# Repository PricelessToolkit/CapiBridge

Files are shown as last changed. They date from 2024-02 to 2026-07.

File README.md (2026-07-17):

<div align="center">
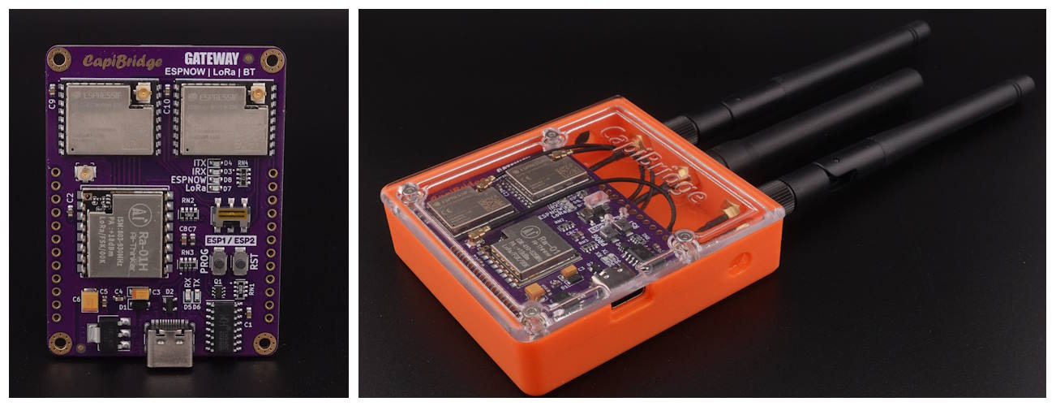
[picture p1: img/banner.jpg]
CapiBridge
  

🤗 Please consider subscribing to my YouTube channel. Your subscription goes a long way toward supporting my work. If you would like to contribute even more, you can also buy me a coffee.
  
  [Shop](https://www.pricelesstoolkit.com) | [YouTube](https://www.youtube.com/watch?v=mJt_VbMeRAU)
  
</div>
<p align="center">
  <a href="https://ko-fi.com/U6U2QLAF8">
    
  </a>
</p>

____________

CapiBridge is an open-source Two-Way gateway for low-power devices. It supports various communication technologies, including LoRa, ESP-NOW, and WiFi. The gateway receives JSON strings from LoRa and ESP-NOW Sensors or DIY devices and publishes them to an MQTT server. It automatically separates the JSON string into dynamic MQTT topics based on keys within the JSON, such as "b" for battery or "m" for motion, making it highly compatible with Home Assistant. This gateway simplifies adding new DIY nodes/sensors to your smart home by standardizing the communication protocol across all your DIY projects, focusing on simplicity and unified protocol handling.

### 🚀 NEW WebUI for Configuration and Monitoring
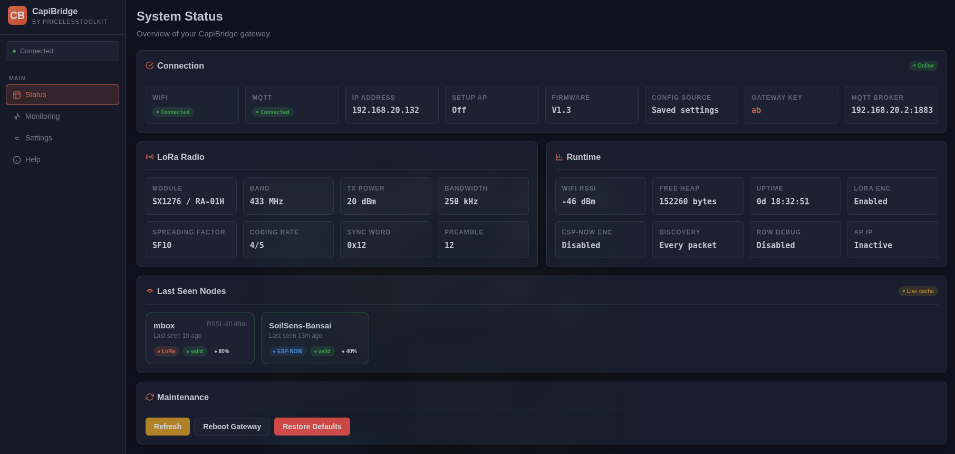
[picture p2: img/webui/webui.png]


____________

## 🛒 Where to buy http://www.PricelessToolkit.com

### Sensors that work out of the box with CapiBridge.
 - [PirBOX-LITE](https://github.com/PricelessToolkit/PirBOX-LITE) LoRa Long-Range Motion Sensor for Mailbox/Garage.....
 - [PirBOX-MAX](https://github.com/PricelessToolkit/PirBOX-MAX) LoRa Long-Range 2-Way Motion Sensor with reed switch inputs and relays
 - [SOILSENS-V5W](https://github.com/PricelessToolkit/SOILSENS-V5W) Soil Moisture Sensor

____________

## Specifications
- 1x LoRa Module 868 or 433MHz
- 2x ESP32-C3
 - ESP1 Free GPIOs
   - IO7, IO10
 - ESP2 Free GPIOs
   - IO10, IO3, IO1, IO0, IO4, IO5, IO6, IO7
- Power Pins 5V, 3.3V, GND
- USB-C with auto reset
- UART switch for selecting ( ESP1 | ESP2 )
- Buttons for flashing and resetting
- Debug LEDs
  - USB - TX, RX
  - ESP1 to ESP2 - TX, RX
  - One LED for LoRa
  - One LED for ESP-NOW

> [!IMPORTANT]
> A high-quality phone charger should be used to ensure a stable 5V power supply.
____________

## 📣 Updates, Bugfixes, and Breaking Changes
- 17.04.2026
  - WebUI for configuration and monitoring.
- 28.03.2026
  - Added support for "Ra-01S" 433Mhz Module.
  - `#define LORA_MODULE LORA_MODULE_SX1268    // Ra-01S 433Mhz Module "433Mhz Version" Module CapiBridge v2`

____________

## Before you start
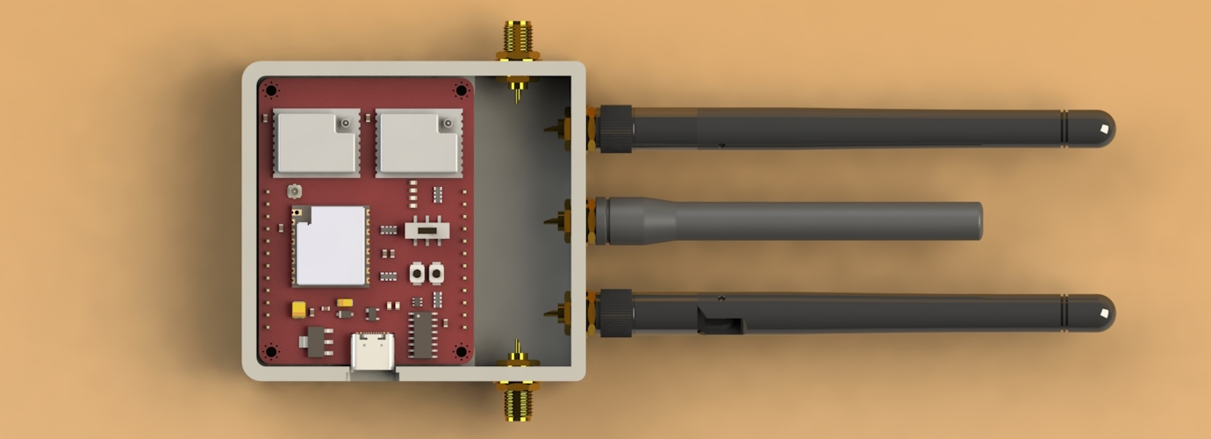
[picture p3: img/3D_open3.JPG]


> [!WARNING]
> ### 🔥Connect all antennas first to prevent damage to the transmitter.🔥

> [!IMPORTANT]
> If you're new to Arduino-related matters, please refrain from asking basic questions like "how to install Arduino IDE". There are already plenty of excellent tutorials available on the internet. If you encounter any issues to which you can't find the answer -> [Here](https://www.google.com/) , feel free to join our [Facebook Group](https://www.facebook.com/groups/pricelesstoolkit) or open a new [discussion](https://github.com/PricelessToolkit/CapiBridge/discussions) topic in the dedicated tab. Remember that providing detailed information about the problem will help me offer more effective assistance. More information equals better help!

## Arduino IDE Configuration

> [!NOTE]
> Arduino IDE 2.3.2

#### Used Arduino Libraries
```c
#include <Arduino.h>
#include <SPI.h>
#include <RadioLib.h>
#include <WiFi.h>
#include <PubSubClient.h>
#include <ArduinoJson.h>
#include <esp_now.h>
```

CapiBridge is based on ESP32-C3, so if you are using ESP32 for the first time, you need to install the ESP32 board and all libraries in your Arduino IDE.
- In your Arduino IDE, go to File> Preferences.
- Enter `https://raw.githubusercontent.com/espressif/arduino-esp32/gh-pages/package_esp32_index.json` into the “Additional Boards Manager URLs” field. Then, click the “OK” button
- Open the Boards Manager. Go to Tools > Board > Boards Manager and search for ESP32 and press the install button for the “esp32 by Expressif Systems“
- Open Library Manager, search for PubSubClient and press the install button, do the same for other libraries.

____________

## ESP1.ino sketch configuration

> [!NOTE]
> For `ESP1.ino`
> Initial configurations are done in the file `config.h` and the rest in WebUI.

#### Initial Configuration

```cpp
///////////////////////////////////////////////////////////////////////////////

//#define LORA_MODULE LORA_MODULE_SX1276    // Ra-01 433 Ra-01H 868/915Mhz "SX1276" Module (orders shipped before Aug 2025)
#define LORA_MODULE LORA_MODULE_SX1262      // Ra-01SH 868/915Mhz "SX1262"  Module CapiBridge v2
//#define LORA_MODULE LORA_MODULE_SX1268    // Ra-01S 433Mhz Module "433Mhz Version" Module CapiBridge v2

#define BAND 868.0                          // 433.0 / 868.0 / 915.0

#define WEBUI_PASSWORD "password"           // Web UI password protection
#define WEBUI_USERNAME "admin"              // Login for the Web UI

#define WIFI_SSID "Your-WIFI-Name"
#define WIFI_PASSWORD "WIFI-Password"

//////////////////////////////////////////////////////////////////////////////

```

## Uploading Code to CapiBridge
> [!WARNING]
> ### 🔥Connect the antenna first to prevent damage to the transmitter.🔥

1. Open ESP1.ino sketch and configure config.h file see https://github.com/PricelessToolkit/CapiBridge?tab=readme-ov-file#esp1ino-sketch-configuration
2. Set the UART switch on the CapiBridge to the 'ESP1' position.
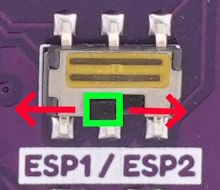
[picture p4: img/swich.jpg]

3. Select board type, COM port and... see the screenshot below.

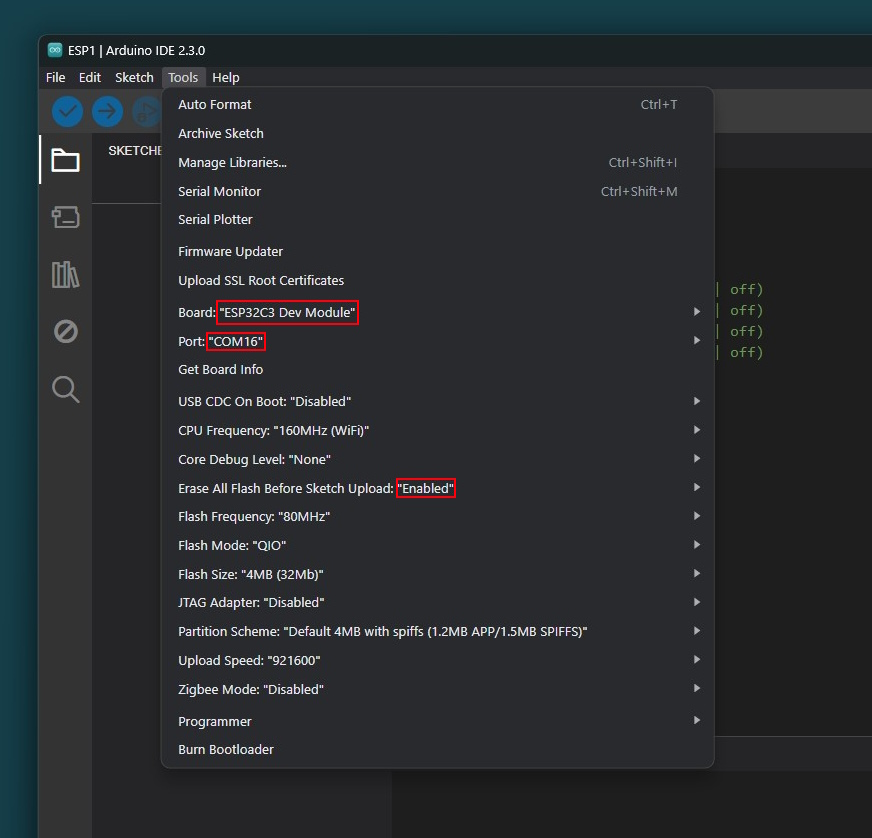
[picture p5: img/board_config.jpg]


4. Click Upload and wait until the upload is done.
5. Set the UART switch on the CapiBridge to the 'ESP2' position.


6. Open ESP2.ino sketch.

> [!NOTE]
> ESP2 for `ESPNOW` requires no initial setup. Once the sketch is uploaded, it automatically prints the MAC address in the serial monitor for integration with ESPNOW nodes/sensors.

8. Click Upload.
9. Set the UART switch back to the ESP1 position to see received JSON messages.

Everything will be ready shortly; the CapiBridge RSSI entity should appear in the Home Assistant MQTT devices list within a minute or two.

> [!NOTE]
> After uploading the code, open the Configuration webpage http://YOUR-CAPIBRIDGE-IP
> and configure the rest.

#### Gateway Separation and Encryption Keys

> [!IMPORTANT]
> Unique `GATEWAY_KEY` within the JSON to differentiate your data from others, and `encryption_key` to globally encrypt the payload. Must match the key in Nodes/Sensors.
> 

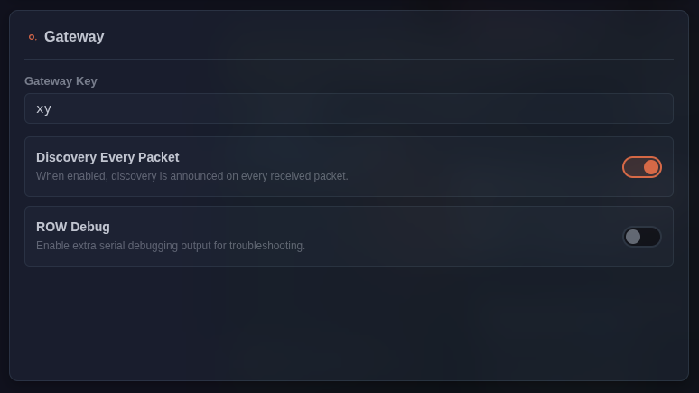
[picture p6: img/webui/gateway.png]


#### 🔐 How to Create Your `encryption_key` Using a Calculator

1. **Choose a few numbers between `1` and `255`**  
   These will be your secret key values.  
   **Example:** `5`, `162`, `77`, `33`

2. **Open your calculator:**
   - **Windows:** Open the **Calculator app** → Click the **☰ menu** → Choose **Programmer**
   - Or use any online converter (Google: _"decimal to hex converter"_)

3. **Convert each number to HEX:**
   - Type your decimal number (e.g., `5`)
   - Switch to **HEX mode**
   - You’ll see the result (e.g., `0x05`)

4. **Use the converted HEX values in WEBUI:**

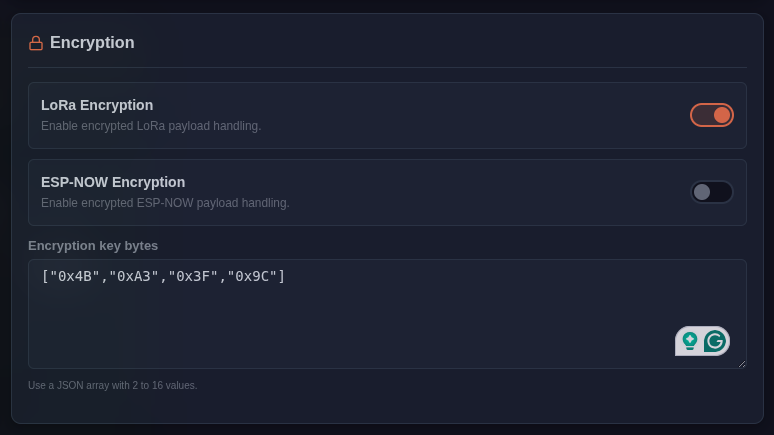
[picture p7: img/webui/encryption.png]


#### WIFI Configuration

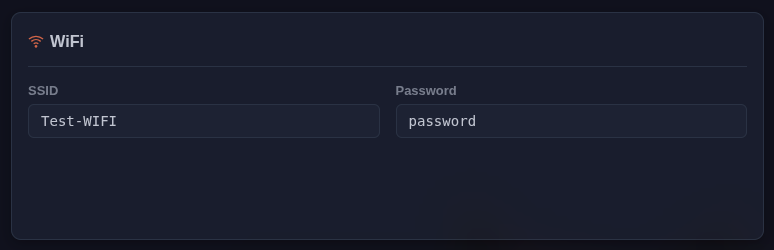
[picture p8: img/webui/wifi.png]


#### MQTT Server Configuration

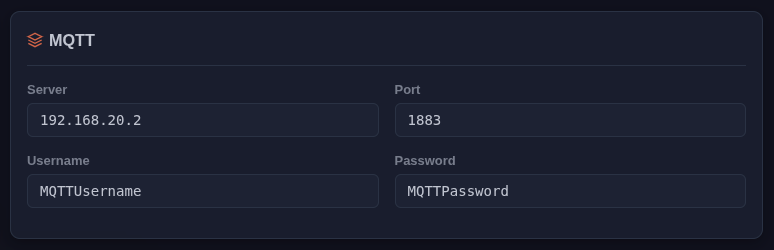
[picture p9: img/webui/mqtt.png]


#### LoRa Configuration

> [!IMPORTANT]
> LoRa configuration must match the configuration in Nodes/Sensors.

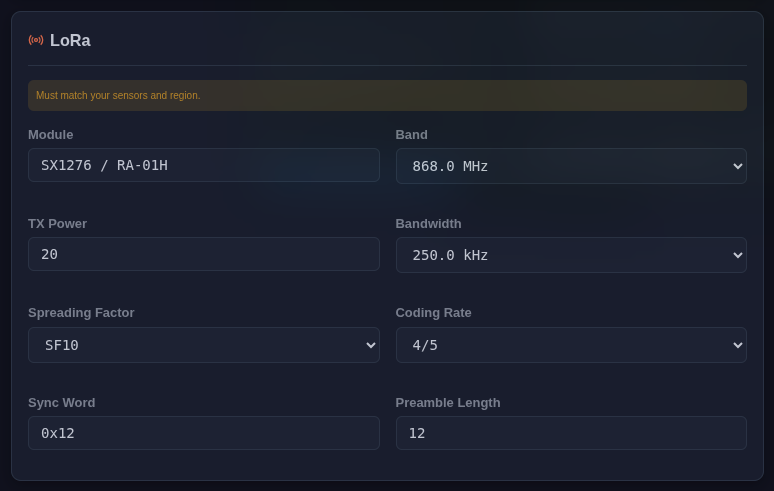
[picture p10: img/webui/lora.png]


> [!IMPORTANT]
> For optimizing the `SPREADING_FACTOR` (SF) in your network, it's crucial not to default to SF11, aiming for maximum distance without considering its downsides. SF11, while extending range, significantly slows down data transmission. For example, if your furthest sensor is only 100 meters away, opting for SF7 is more efficient. SF7 is faster, consuming less power compared to SF11. Therefore, it's essential to choose the SF wisely based on your specific needs and understand the trade-offs. Avoid setting SF11 by default without assessing the impact on speed, power consumption, and time on air (ToA) for others.

____________

## Home Assistant Zero Configuration
> [!NOTE]
> With MQTT-Autodiscovery, there's no need to configure anything in Home Assistant manually. Any sensor or node that sends a JSON string with special keys `('k' for the gateway private key and 'id' for the node name, both of which are mandatory)` will be automatically discovered. Refer to the table below for details, and of course, full ESP32 examples are provided.

## JSON String Sent by a Sensor/Node:

```json
{
  "k": "xy",
  "id": "ESP32",
  "b": "99",
  "rw": "Test123",
  "dr": "on"
}
```
Full Suported MQTT-Autodiscovery List

| Key | Description | Unit of Measurement | Required |
|---|---|---|---|
| `k` | Private Gateway key |  - | Yes |
| `id`  | Node Name |  - | Yes |
| `r` | RSSI | dBm | No |
| `b` | Battery percent | % | No |
| `v` | Voltage | Volts | No |
| `pw`  | Current | mAh | No |
| `l` | Luminance | lux | No |
| `m` | Motion | Binary on/off | No |
| `w` | Weight | grams | No |
| `s` | State | Anything | No |
| `t` | Temperature | °C | No |
| `t2`  | Temperature 2 | °C | No |
| `hu`  | Humidity | % | No |
| `mo`  | Moisture | % | No |
| `rw`  | ROW | Anything | No |
| `bt`  | Button | Binary on/off | No |
| `atm` | Pressure | kph | No |
| `cd`  | Dioxyde de carbone | ppm | No |
| `dr`  | Door | Binary on/off | No |
| `wd`  | Window | Binary on/off | No |
| `vb`  | Vibration | Binary on/off | No |

## ESP-NOW Sensor Example (with optional XOR encryption)

This example broadcasts JSON sensor data from an ESP32 via **ESP-NOW**.  
You can **enable/disable XOR encryption** with a single switch.

- Broadcasts to `FF:FF:FF:FF:FF:FF`
- JSON includes `k` (gateway key) and `id` (device id), plus sample sensor fields
- **ENCRYPTION** toggle controls raw XOR in-place (gateway must use the same key)
- Keep payload under ~249 bytes

<details>
<summary>Minimal Example (with encryption toggle). Click here</summary>

```cpp
#include <Arduino.h>
#include <esp_now.h>
#include <WiFi.h>
#include <esp_wifi.h>
#include <ArduinoJson.h>

// ---------- USER SETTINGS ----------
#define DEVICE_ID            "TestESP"
#define GATEWAY_KEY          "xy"
#define ESPNOW_WIFI_CHANNEL  1
#define SEND_PERIOD_MS       5000

// XOR encryption toggle and key
#define ENCRYPTION 0   // 0 = off, 1 = on
#define encryption_key_length 4
#define encryption_key { 0x4B, 0xA3, 0x3F, 0x9C }
// -----------------------------------

// Broadcast MAC
static const uint8_t BROADCAST_MAC[6] = {0xFF,0xFF,0xFF,0xFF,0xFF,0xFF};
unsigned long lastSend = 0;

// XOR in place (raw bytes)
static inline void xorInPlace(uint8_t* data, size_t len) {
  static const uint8_t key[] = encryption_key;
  const size_t K = encryption_key_length;
  for (size_t i = 0; i < len; ++i) data[i] ^= key[i % K];
}

// Build small JSON payload (add your real sensor values)
static size_t buildSensorJson(char* out, size_t cap) {
  JsonDocument doc;          // ArduinoJson v7 style
  doc["k"]  = GATEWAY_KEY;   // REQUIRED: gateway private key
  doc["id"] = DEVICE_ID;     // REQUIRED: node/device id
  doc["t"]  = 21.5;          // temperature °C (example)
  doc["hu"] = 46;            // humidity %  (example)
  return serializeJson(doc, out, cap);
}

static bool sendBroadcast() {
  char buf[160];
  size_t len = buildSensorJson(buf, sizeof(buf));
  if (len == 0 || len >= sizeof(buf)) return false;

  // Optional debug: plaintext
  // Serial.write((const uint8_t*)buf, len); Serial.println();

  // Toggle XOR encryption
  #if ENCRYPTION
    xorInPlace(reinterpret_cast<uint8_t*>(buf), len);
  #endif

  return esp_now_send(BROADCAST_MAC, reinterpret_cast<const uint8_t*>(buf), len) == ESP_OK;
}

// Send callback (handles both IDF v4 and v5 cores)
#if defined(ESP_IDF_VERSION_MAJOR) && (ESP_IDF_VERSION_MAJOR >= 5)
void onDataSent(const wifi_tx_info_t*, esp_now_send_status_t status) {
  Serial.println(status == ESP_NOW_SEND_SUCCESS ? "SUCCESS" : "FAIL");
}
#else
void onDataSent(const uint8_t*, esp_now_send_status_t status) {
  Serial.println(status == ESP_NOW_SEND_SUCCESS ? "SUCCESS" : "FAIL");
}
#endif

void setup() {
  Serial.begin(115200);
  WiFi.persistent(false);
  WiFi.mode(WIFI_STA);
  esp_wifi_set_ps(WIFI_PS_NONE);
  esp_wifi_start();

  // Lock to gateway's Wi-Fi channel
  esp_wifi_set_promiscuous(true);
  esp_wifi_set_channel(ESPNOW_WIFI_CHANNEL, WIFI_SECOND_CHAN_NONE);
  esp_wifi_set_promiscuous(false);

  if (esp_now_init() != ESP_OK) {
    Serial.println("ESP-NOW init failed");
    while (true) delay(1000);
  }
  esp_now_register_send_cb(onDataSent);

  // Add broadcast peer (unencrypted at ESP-NOW level; XOR is app-layer)
  esp_now_peer_info_t peer{};
  memcpy(peer.peer_addr, BROADCAST_MAC, 6);
  peer.ifidx   = WIFI_IF_STA;
  peer.channel = ESPNOW_WIFI_CHANNEL;
  peer.encrypt = false;
  esp_now_add_peer(&peer);
}

void loop() {
  if (millis() - lastSend >= SEND_PERIOD_MS) {
    lastSend = millis();
    bool ok = sendBroadcast();
    Serial.println(ok ? "Sent" : "Send failed");
  }
}

```
</details>

👉 full example with all supported keys is available in the `Node_Examples` folder.

## LoRa Sensor Example (with optional XOR encryption)
You can find working code examples in the following repositories:  
- [MailBoxGuard for "CapiBridge"](https://github.com/PricelessToolkit/MailBoxGuard/blob/main/Code/CapiBridge/Mailbox_Guard_Sensor_CapiBridge/Mailbox_Guard_Sensor_CapiBridge.ino)
- [PirBOX-LITE](https://github.com/PricelessToolkit/PirBOX-LITE)  
- [PirBOX-MAX](https://github.com/PricelessToolkit/PirBOX-MAX)  

---

## XOR Encryption / Decryption Example

This snippet shows how to use a simple **XOR cipher** with ESP-NOW.  
Both sender and receiver must use the **same key**.

- `xorInPlace()` encrypts or decrypts data in-place.  
- Call it **before sending** to encrypt.  
- Call it **after receiving** to decrypt.  

---

```cpp
// --- XOR helper (must match on sender + receiver) ---
#define encryption_key_length 4
#define encryption_key { 0x4B, 0xA3, 0x3F, 0x9C }

static inline void xorInPlace(uint8_t* data, size_t len) {
  static const uint8_t key[] = encryption_key;
  const size_t K = encryption_key_length;
  for (size_t i = 0; i < len; ++i) data[i] ^= key[i % K];
}

// --- SENDER ---
void sendExample() {
  char msg[] = "hello world";
  size_t len = strlen(msg);

  // Encrypt before sending
  xorInPlace((uint8_t*)msg, len);
  esp_now_send(BROADCAST_MAC, (uint8_t*)msg, len);
}

// --- RECEIVER ---
void onDataRecv(const uint8_t* mac, const uint8_t* data, int len) {
  char buf[128];
  memcpy(buf, data, len);

  // Decrypt after receiving
  xorInPlace((uint8_t*)buf, len);
  buf[len] = '\0';  // make string safe

  Serial.print("Decrypted: ");
  Serial.println(buf);
}
```

---

## 🔁 2-Way Communication – Sending Commands

To send a command via **LoRa** or **ESP-NOW**, publish a JSON payload to the following MQTT topic:

```
homeassistant/sensor/CapiBridge/command
```

LoRa Payload

```json
{"k":"xy","id":"PirBoxM","rm":"lora","com":"xxxxxx"}
```
ESP-NOW payload
```json
{"k":"xy","id":"PirBoxM","rm":"espnow","com":"xxxxxx"}
```

Descriptions

| Key | Description | Example |
|---|---|---|
| `k` | Private gateway key (auth) | `"xy"` |
| `id`  | Target node name (device ID) | `"PirBoxM"` |
| `rm`  | Radio mode (`lora` / `espnow`)  | `"lora", "espnow"` |
| `com` | Command code (text/number) | `"xxxxxx"`  |

To send commands through the Home Assistant Dashboard, use the button example below.

```yaml

type: horizontal-stack
cards:
  - show_name: true
    show_icon: true
    type: button
    name: Relay 1
    icon: mdi:numeric-1-box
    tap_action:
      action: call-service
      service: mqtt.publish
      service_data:
        topic: homeassistant/sensor/CapiBridge/command
        payload: "{\"k\":\"xy\",\"id\":\"PirBoxM\",\"rm\":\"lora\",\"com\":\"10\"}"
  - type: button
    name: Relay 2
    icon: mdi:numeric-2-box
    tap_action:
      action: call-service
      service: mqtt.publish
      service_data:
        topic: homeassistant/sensor/CapiBridge/command
        payload: "{\"k\":\"xy\",\"id\":\"PirBoxM\",\"rm\":\"lora\",\"com\":\"01\"}"
  - type: button
    name: Relay 1 and 2
    icon: mdi:numeric-3-box
    tap_action:
      action: call-service
      service: mqtt.publish
      service_data:
        topic: homeassistant/sensor/CapiBridge/command
        payload: "{\"k\":\"xy\",\"id\":\"PirBoxM\",\"rm\":\"lora\",\"com\":\"11\"}"
```

> [!NOTE]
> Please note that when sending a JSON payload from the HA dashboard, the payload needs to be slightly changed; you need to put the payload into "" and add \ before every ". For example `"{\"k\":\"xy\",\"id\":\"PirBoxM\",\"rm\":\"lora\",\"com\":\"11\"}"`

# Do you want to assemble it yourself?
This project is open-source, allowing you to assemble CapiBridge on your own. To simplify this process, I've provided an "Interactive HTML Boom File" located in the PCB folder. This interactive file helps you identify where to solder each component and polarity, reducing the chances of errors to a minimum. But if you don't feel confident in assembling it yourself, you can always opt to purchase a pre-assembled board from my Shop https://www.pricelesstoolkit.com

## Schematic
<details>
  <summary>View schematic. Click here</summary>
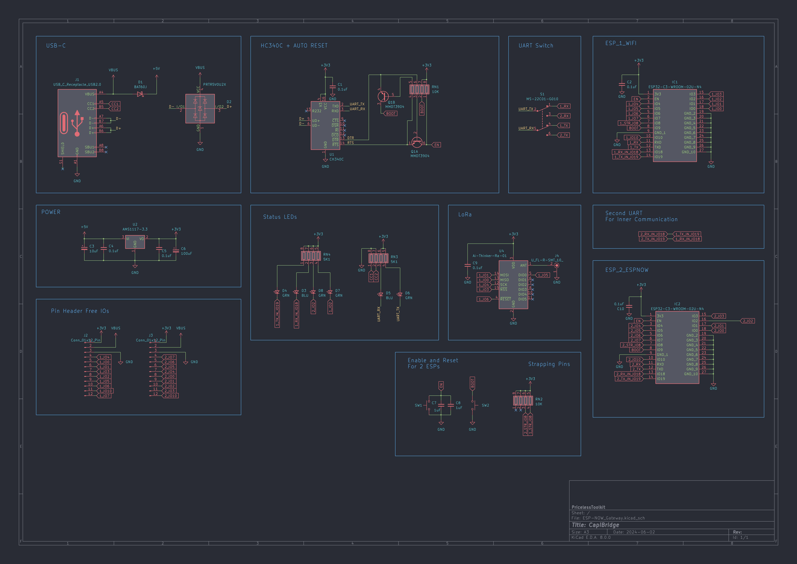
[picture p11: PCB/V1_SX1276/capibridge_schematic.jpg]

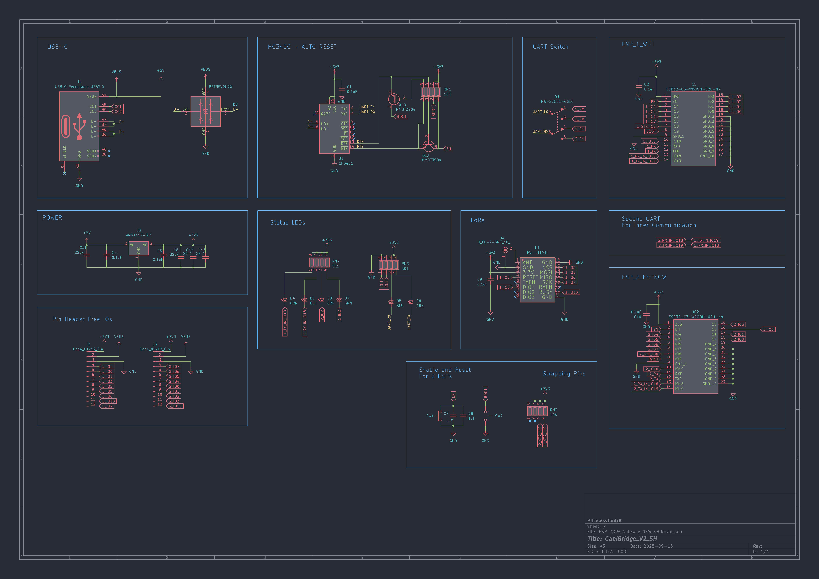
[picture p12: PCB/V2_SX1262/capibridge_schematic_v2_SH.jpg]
 
</details>

____________

  Links for antennas and cables.

 - 2.4Ghz Antenna + Cable https://s.click.aliexpress.com/e/_DE0sJ7N
 - Cable UFL to SMA https://s.click.aliexpress.com/e/_Dnee0tV
 - Antenna 433 MHz SMA male https://s.click.aliexpress.com/e/_Dm2X9vv
 - Antenna 868 MHz SMA male https://s.click.aliexpress.com/e/_Dczm4y7

____________

## Troubleshooting
If your DIY sensor/assembly is not showing up in Home Assistant, here are some tips that may help you find the problem.
1. Check if the node LoRa settings are the same as the LoRa Gateway config, like Frequency, and spreading factor...
2. Connect CapiBridge to PC with switch position selected ESP1, open Arduino IDE Serial monitor "Speed 115200 baud" and check received JSON strings for errors.
3. Download MQTT Explorer and connect to your MQTT server. Check the `homeassistant/sensor/Your_Node_Name` topic for any errors.

4. If you have a spare ESP32, you can monitor raw ESP-NOW broadcast traffic along with the sender’s MAC addresses.  

<details>
<summary>Simple ESP32 code that prints all ESP-NOW broadcast traffic — click to expand</summary>

```cpp

#include <Arduino.h>
#include <esp_now.h>
#include <WiFi.h>
#include <esp_wifi.h>
#include <esp_err.h>

// ---------------- Pins / Serial ----------------
#define LED_PIN 2
#define BAUD    115200

// ---------------- ESPNOW ----------------
#define ESPNOW_WIFI_CHANNEL 1
static const uint8_t BROADCAST_MAC[6] = {0xFF,0xFF,0xFF,0xFF,0xFF,0xFF};

unsigned long LedStartTime = 0;

// -------- Helpers --------
static bool printStaMac() {
  uint8_t mac[6] = {0};
  if (esp_wifi_get_mac(WIFI_IF_STA, mac) != ESP_OK) return false;
  bool allZero = true; for (int i=0;i<6;i++) if (mac[i]) { allZero=false; break; }
  Serial.print("My MAC: ");
  if (allZero) Serial.println("00:00:00:00:00:00");
  else { for (int i=0;i<6;i++){ if(i) Serial.print(':'); Serial.printf("%02X", mac[i]); } Serial.println(); }
  return !allZero;
}

// -------- Callbacks --------
#if defined(ESP_IDF_VERSION_MAJOR) && (ESP_IDF_VERSION_MAJOR >= 5)
// IDF v5 / Arduino-ESP32 3.x
void OnDataRecv(const esp_now_recv_info_t *info, const uint8_t *data, int len) {
  char buf[256];
  if (len >= (int)sizeof(buf)) len = sizeof(buf) - 1;
  memcpy(buf, data, len);
  buf[len] = '\0';

  if (info && info->src_addr) {
    for (int i=0; i<6; i++) {
      if (i) Serial.print(':');
      Serial.printf("%02X", info->src_addr[i]);
    }
    Serial.print(" -> ");
  }

  Serial.println(buf);

  digitalWrite(LED_PIN, LOW);   // blink
  LedStartTime = millis();
}
#else
// IDF v4 / Arduino-ESP32 2.x
void OnDataRecv(const uint8_t *mac, const uint8_t *data, int len) {
  char buf[256];
  if (len >= (int)sizeof(buf)) len = sizeof(buf) - 1;
  memcpy(buf, data, len);
  buf[len] = '\0';

  if (mac) {
    for (int i=0; i<6; i++) {
      if (i) Serial.print(':');
      Serial.printf("%02X", mac[i]);
    }
    Serial.print(" -> ");
  }

  Serial.println(buf);

  digitalWrite(LED_PIN, LOW);   // blink
  LedStartTime = millis();
}
#endif

void setup() {
  Serial.begin(BAUD);
  delay(1000);
  while (!Serial && millis() < 5000) { delay(10); }

  pinMode(LED_PIN, OUTPUT);
  digitalWrite(LED_PIN, HIGH); // LED off

  WiFi.persistent(false);
  WiFi.mode(WIFI_STA);
  esp_wifi_set_ps(WIFI_PS_NONE);
  esp_wifi_start();
  delay(50);

  if (!printStaMac()) {
    esp_wifi_stop(); delay(50); esp_wifi_start(); delay(100);
    printStaMac();
  }

  esp_wifi_set_promiscuous(true);
  esp_wifi_set_channel(ESPNOW_WIFI_CHANNEL, WIFI_SECOND_CHAN_NONE);
  esp_wifi_set_promiscuous(false);

  Serial.print("ESPNOW Channel: "); Serial.println(ESPNOW_WIFI_CHANNEL);

  if (esp_now_init() != ESP_OK) {
    for(;;) delay(1000);
  }

  esp_now_peer_info_t bcast{};
  memcpy(bcast.peer_addr, BROADCAST_MAC, 6);
  bcast.ifidx   = WIFI_IF_STA;
  bcast.channel = ESPNOW_WIFI_CHANNEL;
  bcast.encrypt = false;
  esp_err_t e = esp_now_add_peer(&bcast);
  (void)e; // ignore errors

  esp_now_register_recv_cb(OnDataRecv);
}

void loop() {
  if (millis() - LedStartTime >= 100) digitalWrite(LED_PIN, HIGH);
}

```
</details>



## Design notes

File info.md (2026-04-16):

## Sensors that work out of the box with CapiBridge:

- [PirBOX-LITE](https://github.com/PricelessToolkit/PirBOX-LITE) - LoRa long-range motion sensor for mailbox / garage
- [PirBOX-MAX](https://github.com/PricelessToolkit/PirBOX-MAX) - LoRa long-range 2-way motion sensor with reed switch inputs and relays
- [SOILSENS-V5W](https://github.com/PricelessToolkit/SOILSENS-V5W) - Soil moisture sensor

## HowTo

- [JSON String Sent by a Sensor/Node](https://github.com/PricelessToolkit/CapiBridge/tree/main?tab=readme-ov-file#json-string-sent-by-a-sensornode)
- [Nod Examples](https://github.com/PricelessToolkit/CapiBridge/tree/main/code/Node_Examples)
- [2-Way Communication – Sending Commands](https://github.com/PricelessToolkit/CapiBridge?tab=readme-ov-file#-2-way-communication--sending-commands)
- [Create Your encryption_key](https://github.com/PricelessToolkit/CapiBridge/tree/main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)
- [Troubleshooting](https://github.com/PricelessToolkit/CapiBridge/tree/main?tab=readme-ov-file#troubleshooting)

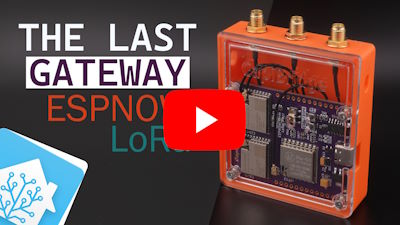
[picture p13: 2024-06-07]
img/video.jpg

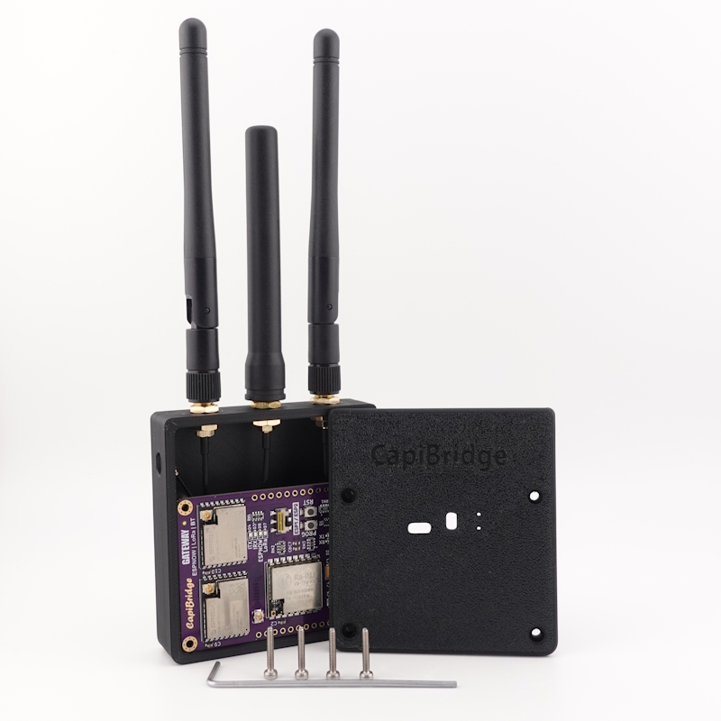
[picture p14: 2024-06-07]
img/Nice Images/CapiBridge_Full_Kit_19.jpg

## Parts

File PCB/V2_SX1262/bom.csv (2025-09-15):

Designator | Footprint | Quantity | Value | LCSC Part #
C1, C10, C2, C4, C5, C9 | 0603 | 6 | 0.1uF
C11, C12, C13, C6 | 1206 | 4 | 22uF
C7, C8 | 0603 | 2 | 1uF
D2 | SOT-143 | 1 | PRTR5V0U2X
D3, D5 | 0603 | 2 | BLU
D4, D6, D7, D8 | 0603 | 4 | GRN
IC1, IC2 | ESP32C3WROOM02UN4 | 2 | ESP32-C3-WROOM-02U-N4
J1 | USB_C_Receptacle_HRO_TYPE-C-31-M-12 | 1 | USB_C_Receptacle_USB2.0
J2, J3 | PinHeader_1x12_P2.54mm_Vertical | 2 | Conn_01x12_Pin
J4 | Coax_Conn_U.FL | 1 | U_FL-R-SMT_10_ | U.FL-R-SMT(10)
L1 | Ai-Thinker-Ra-01-LoRa | 1 | Ra-01SH
Q1 | SOT-363_SC-70-6 | 1 | MMDT3904
RN1, RN2 | RESCAXE80P320X160X70-8N | 2 | 10K
RN3, RN4 | RESCAXE80P320X160X70-8N | 2 | 5K1
S1 | MS-22C01-G010 | 1 | MS-22C01-G010 | MS-22C01-G010
SW1, SW2 | TS342A2P-WZ | 2 | TS342A2P-WZ
U1 | SOIC-16_3.9x9.9mm_P1.27mm | 1 | CH340C
U2 | SOT-223-3_TabPin2 | 1 | AMS1117-3.3

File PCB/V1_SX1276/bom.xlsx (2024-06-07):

Part IPN | Part Name | Quantity | Reference | Manufacturer_0 | MPN_0
 | CapiBridge - PCB | 1.0
CAP-000219-00 | Capacitor 0603_100nF_10%_50V_X7R - SMD/SMT ROHS | 6.0 | C1, C2, C4, C5, C9, C10 | YAGEO | CC0603KRX7R9BB104
CAP-000263-00 | Capacitor 0603_1uF_10%_25V_X7R - SMD/SMT ROHS | 2.0 | C7, C8 | FH (Guangdong Fenghua Advanced Tech) | 0603B105K250NT
CAP-000290-00 | Tantalum Capacitor 10uF_10V_3R_10%_CASE-A-3216 100kHz ROHS | 1.0 | C3 | Kyocera AVX | TAJA106K010RNJ
CAP-000289-00 | Tantalum Capacitor 100uF_6.3V_250mR_20%_CASE-B-3528 100kHz ROHS | 1.0 | C6 | Kyocera AVX | TPSB107M006R0250
DIO-000053-00 | LED 0603_55mW_Yellow-Green - ROHS | 4.0 | D4, D6, D7, D8 | XINGLIGHT | XL-1608SYGC-06
DIO-000201-00 | LED 0603_80mW_Blue XL-1608UBC-04 ROHS | 2.0 | D3, D5 | XINGLIGHT | XL-1608UBC-04
DIO-000106-00 | Schottky Diode 1N5819W_40V_1A_SOD-123F (SBD) ROHS | 1.0 | D1 | Shandong Jingdao Microelectronics | 1N5819W
PRO-000090-00 | TVS Protection PRTR5V0U2X 5V SOT-143 ROHS | 1.0 | D2 | UMW(Youtai Semiconductor Co., Ltd.) | PRTR5V0U2X
ICS-000049-00 | USB UART Transceiver CH340C_2Mbps_SOP-16 - ROHS | 1.0 | U1 | WCH(Jiangsu Qin Heng) | CH340C
PWR-000089-00 | Voltage Regulator AMS1117-3.3V 1A 3.3V SOT-223 (LDO) ROHS | 1.0 | U2 | WPMtek(Wei Pan Microelectronics) | AMS1117-3.3V
RFC-000112-00 | LoRa Module Ra-01H 868MHz SMD-16P ROHS | 1.0 | U4 | Ai-Thinker | Ra-01H
MEC-000122-00 | Tactile Switche TS342A2P-WZ NO 50mA Brick nogging SPST SMD ROHS | 2.0 | SW1, SW2 | SHOU HAN | TS342A2P-WZ
WIFI-000274-00 | WIFI Module ESP32-C3-WROOM-02U-N4 4MB SPI flash, IPEX antenna SMD | 2.0 | IC1, IC2 | Espressif Systems | ESP32-C3-WROOM-02U-N4
RES-000291-00 | Resistor Network 0603x4_10k_1% 62.5mW ROHS | 2.0 | RN1, RN2 | YAGEO | YC164-FR-0710KL
RES-000301-00 | Resistor Network 0603x4_5.1K_5%_62.5mW ±200ppm/℃ ROHS | 2.0 | RN3, RN4 | UNI-ROYAL(Uniroyal Elec) | 4D03WGJ0512T5E
TRA-000072-00 | Transistors 2 NPN MMDT3904-7-F 40V 200mA SOT-323-6 ROHS | 1.0 | Q1 | Diodes Incorporated | MMDT3904-7-F
MEC-000280-00 | Slide Switche MS-22C01-G010 1A DPDT 6V Brick nogging SMD ROHS | 1.0 | S1 | G-Switch | MS-22C01-G010
CON-000058-00 | Connector Type-C_16P_USB_2.0_5A - ROHS | 1.0 | J1 | G-Switch | GT-USB-7010E
CON-000299-00 | SMD RF Connector IPEX U.FL-R-SMT-1(10) 6GHz 50Ω 2mm Coaxial Connectors ROHS | 1.0 | J4 | HRS(Hirose) | U.FL-R-SMT-1(10)

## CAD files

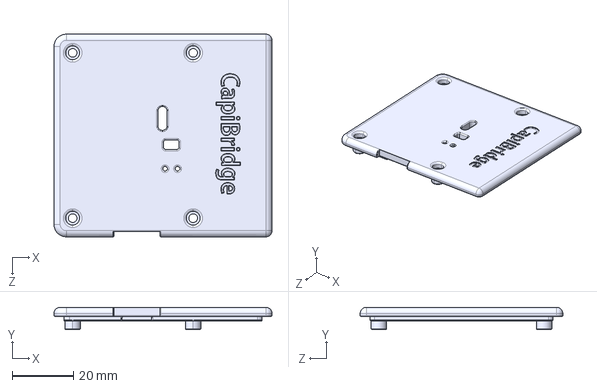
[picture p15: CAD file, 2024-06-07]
3D/CapiBridge_Case_lit.STEP
71.0 x 7.30 x 66.0 mm

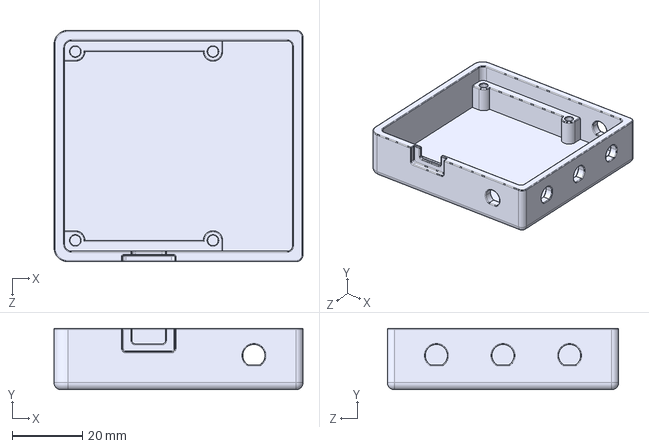
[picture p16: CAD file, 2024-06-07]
3D/CapiBridge_Case.STEP
71.0 x 17.5 x 66.0 mm

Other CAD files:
3D/CapiBridge_Case.STL
3D/CapiBridge_Case_lit.STL

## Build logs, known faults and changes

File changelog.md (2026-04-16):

## Latest Update "18.04.2026"

- Web UI added
  - Runtime settings page added
  - Dark and light theme toggle added
  - Prettified payloads view added
  - Raw View live terminal added

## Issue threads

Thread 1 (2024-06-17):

Compilation error: 'esp_now_recv_info_t' does not name a type; did you mean 'esp_netif_ip_info_t'?

RonnieLast, 2024-06-17:
Hi, I received the CapiBridge this morning; it looks very good and well designed.
I flashed ESP1 no problem, ESP2 is encountering an error during compilation.

```
/home/user_me/Arduino/CapiBridge/ESP1/ESP2.ino:23:23: error: 'esp_now_recv_info_t' does not name a type; did you mean 'esp_netif_ip_info_t'?
 void OnDataRecv(const esp_now_recv_info_t *info, const uint8_t *incomingData, int len) {
                       ^~~~~~~~~~~~~~~~~~~
                       esp_netif_ip_info_t
/home/user_me/Arduino/CapiBridge/ESP1/ESP1.ino: In function 'void parseIncomingPacket(String)':
/home/user_me/Arduino/CapiBridge/ESP1/ESP1.ino:669:3: warning: 'template<unsigned int N> class ArduinoJson::V704PB2::StaticJsonDocument' is deprecated: use JsonDocument instead [-Wdeprecated-declarations]
   StaticJsonDocument<1024> doc; // Adjust size as necessary
   ^~~~~~~~~~~~~~~~~~
In file included from /home/user_me/Arduino/libraries/ArduinoJson/src/ArduinoJson.hpp:53,
                 from /home/user_me/Arduino/libraries/ArduinoJson/src/ArduinoJson.h:9,
                 from /home/user_me/Arduino/CapiBridge/ESP1/ESP1.ino:12:
/home/user_me/Arduino/libraries/ArduinoJson/src/ArduinoJson/compatibility.hpp:63:58: note: declared here
 class ARDUINOJSON_DEPRECATED("use JsonDocument instead") StaticJsonDocument
                                                          ^~~~~~~~~~~~~~~~~~
/home/user_me/Arduino/CapiBridge/ESP1/ESP2.ino: At global scope:
/home/user_me/Arduino/CapiBridge/ESP1/ESP2.ino:11:15: error: redefinition of 'long unsigned int LedStartTime'
 unsigned long LedStartTime = 0;
               ^~~~~~~~~~~~
/home/user_me/Arduino/CapiBridge/ESP1/ESP1.ino:32:15: note: 'long unsigned int LedStartTime' previously defined here
 unsigned long LedStartTime = 0;
               ^~~~~~~~~~~~
/home/user_me/Arduino/CapiBridge/ESP1/ESP2.ino:23:23: error: 'esp_now_recv_info_t' does not name a type; did you mean 'esp_now_peer_info_t'?
 void OnDataRecv(const esp_now_recv_info_t *info, const uint8_t *incomingData, int len) {
                       ^~~~~~~~~~~~~~~~~~~
                       esp_now_peer_info_t
/home/user_me/Arduino/CapiBridge/ESP1/ESP2.ino:35:6: error: redefinition of 'void setup()'
 void setup() {
      ^~~~~
/home/user_me/Arduino/CapiBridge/ESP1/ESP1.ino:117:6: note: 'void setup()' previously defined here
 void setup() {
      ^~~~~
/home/user_me/Arduino/CapiBridge/ESP1/ESP2.ino: In function 'void setup()':
/home/user_me/Arduino/CapiBridge/ESP1/ESP2.ino:51:28: error: invalid conversion from 'void (*)(const int*, const uint8_t*, int)' {aka 'void (*)(const int*, const unsigned char*, int)'} to 'esp_now_recv_cb_t' {aka 'void (*)(const unsigned char*, const unsigned char*, int)'} [-fpermissive]
   esp_now_register_recv_cb(OnDataRecv);
                            ^~~~~~~~~~
In file included from /home/user_me/Arduino/CapiBridge/ESP1/ESP2.ino:2:
/home/user_me/Arduino/hardware/espressif/esp32/tools/sdk/esp32c3/include/esp_wifi/include/esp_now.h:144:54: note:   initializing argument 1 of 'esp_err_t esp_now_register_recv_cb(esp_now_recv_cb_t)'
 esp_err_t esp_now_register_recv_cb(esp_now_recv_cb_t cb);
                                    ~~~~~~~~~~~~~~~~~~^~
/home/user_me/Arduino/CapiBridge/ESP1/ESP2.ino: At global scope:
/home/user_me/Arduino/CapiBridge/ESP1/ESP2.ino:59:6: error: redefinition of 'void loop()'
 void loop() {
      ^~~~
/home/user_me/Arduino/CapiBridge/ESP1/ESP1.ino:704:6: note: 'void loop()' previously defined here
 void loop() {
      ^~~~

exit status 1

Compilation error: 'esp_now_recv_info_t' does not name a type; did you mean 'esp_netif_ip_info_t'?
```
I don't think it's a library issue, but willing to be wrong on that. Googling the compilation error appears to point to a code issue.

Arduino IDE is 2.3.2 (flatpak).

PricelessToolkit, 2024-06-17:
Hi, Thank you for supporting my work!. It looks like you've run into a few issues with the compilation. With the latest Arduino IDE on Windows, it compiles without a problem. It's highly likely that the issue you're facing is related to the library on your setup. I recommend checking that all your libraries are up to date and compatible with your current Arduino IDE version.

Hope this helps!

PricelessToolkit, 2024-06-17:
2. The Arduino IDE does not handle multiple firmware files in the same directory well.  /home/user_me/Arduino/CapiBridge/ESP1/ESP2.ino << file placement is not correct.

RonnieLast, 2024-06-17:
Good catch on the directory - I miscreated that alright.

I have it working now but it was a different problem; I selected "ESP32C3 Dev Module" from "ESP32 Arduino (in Sketchbook)" rather than from "esp32". When I corrected this it compiled and uploaded ok.

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

Another thing to mention is that you might need to tell users to move the UART selector switch back from ESP2 to ESP1 so that they can see the serial output from ESP1 after installing the firmware.

PricelessToolkit, 2024-06-17:
I'm glad it worked, I added point 8 to the instructions "Set the UART switch back to the ESP1 position to see received JSON messages."

Closed 2024-06-17.

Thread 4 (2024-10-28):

Compilation error: LoRa.h: No such file or directory

servebeer, 2024-10-28:
I tried to compile the sketch for my new CapiBridge, but it failed. I am using ESP32C3 Dev Module and ESP1.ino w/ config.h. When I try to compile the sketch, I get this error:

C:\Users\jon.IrishTech\Downloads\CapiBridge-main\CapiBridge-main\code\Gateway\ESP1\ESP1.ino:9:10: fatal error: LoRa.h: No such file or directory
    9 | #include <LoRa.h>
      |          ^~~~~~~~
compilation terminated.
exit status 1

Compilation error: LoRa.h: No such file or directory

I don't use Arduino IDE much, so I am sure it is an issue with the way that I have it configured?

Jon

PricelessToolkit, 2024-10-28:
Hi Jon, Thank you for your support!!.
You need to install all the necessary libraries. https://github.com/PricelessToolkit/CapiBridge?tab=readme-ov-file#used-arduino-libraries

servebeer, 2024-10-28:
Thanks for the quick reply! As I mentioned, I am new to Arduino so I
imagine that I am going to have several dumb questions. I will will try
to do abetter job of reading all the documentation before posting as well.

Jon

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

--
v/r
Jon

PricelessToolkit, 2024-10-28:
or just copy https://github.com/PricelessToolkit/CapiBridge/tree/main/lib into the Arduino library folder.

servebeer, 2024-10-28:
So, if I go to the Library Manager and search for LoRa, about 20 libraries show up. I was going to try to copy the link above to the Arduino library folder, but I am not exactly sure where that is. I am thinking maybe : C:\Program Files\Arduino IDE\resources\app\lib but wanted to be certain.

servebeer, 2024-10-28:
Just figured it out ;-) I restarted IDE and it is updating those libraries, so I think I am good to go.

servebeer, 2024-10-28:
Last question for today, I promise. How long does it normally take to compile a sketch? Mine has been running for over 20 minutes now with no errors or any type of output.
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

servebeer, 2024-10-28:
I just figured out my problem. I do not use a username and password for my MQTT server as it is only exposed on my internal LAN. I commented out lines 11 and 12 in config.h and that cause issues with line 99 in ESP1.ino. I will go back into my MQTT server config and enable a username and password.

PricelessToolkit, 2024-10-28:
on my pc, it takes 20 seconds not minutes!!!!!, username and password are mandatory.
PS: question quantity is not limited! but sometimes I can't answer right away I have a day job :)

servebeer, 2024-10-28:
That is pretty crazy. I guess as long as it works... I appreciate the help and answering right away is no big deal. I realize that you are multiple hours ahead of me, so I can definitely understand.

PricelessToolkit, 2024-10-30:
Did you manage to set everything up? can I close this issue ??

servebeer, 2024-10-31:
Hello,
Sorry about missing this yesterday. I think I am good right now. I will be out of tome on buisness for most of November, so it will be awhile before I can verify everything. It took me awhile to figure out how to get authentication working on my MQTT instance (Mosquito), but I think that is all sorted out now.

Thanks!
Jon

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

Closed 2024-10-31.

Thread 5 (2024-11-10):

feature request: add RJ45 and/or POE to the CapiBridge

steuerzentrale, 2024-11-10:
Hi there

I use your superb mailbox-sensor and the LILYGO TTGO LoRa32 V2.1 1.6.1. My goal is to replace as many wireless components as possible as I have experienced Wifi-issues at my home.

Do you plan to offer CapiBridge with an RJ45 and/or POE-option? It would give the user the flexibility in terms of connectivity and would be a huge USP as there are almost no LoRa-gateways with RJ45 and/or POE on the market.

Best,
Andrew

PricelessToolkit, 2024-11-13:
The concept is solid, and it was designed with expandability in mind. The only challenge is finding enough time to bring everything to completion. If time allows, I plan to launch it as an open-source project, enabling the community members to order assembled boards from  Chinese manufacturers.

Closed 2024-11-13.

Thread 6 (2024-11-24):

Issue with MQTT auto discovery with a simple diy pushbutton sender

ppkstat, 2024-11-24:
I have my Capibridge and it works great with the provided examples (such as the ESP32_ESP-NOW_Example.ino).

Trying to familiarize myself with the protocol, hoping to make some DIY devices for my new gateway I connected a pushbutton to an ESP32 and wrote some code following the guidelines for the receiver side. It works and the Capibridge is getting the following JSON (the leds are also blinking):

`ESP-NOW Message: {"k":"xy","id":"testbutton","bt":"on"}`

Now theoretically this should be enough for the device to be auto discovered in homeassistant but I am getting nothing. Opening the MQTT explorer I am seeing that it publishes on the homeassistant/binary_sensor topic instead the homeassistant/sensor. This is an example:
`{
  "name": "Button",
  "device_class": "none",
  "icon": "mdi:button",
  "state_topic": "homeassistant/sensor/testbutton/button",
  "unique_id": "testbutton_bt",
  "payload_on": "on",
  "payload_off": "off",
  "device": {
    "identifiers": [
      "testbutton"
    ],
    "name": "testbutton",
    "mdl": "testbutton",
    "mf": "PricelessToolkit"
  }
}
`
Would you be kind enough to tell me if I am doing anything wrong? Perhaps it’s a bug. Is the "device_class": "none" ok for homeassistant?

ppkstat, 2024-11-24:
So happy to be able to help you and contribute!

I flashed. The mqtt message changed but still nothing on HA:
`{
  "name": "Button",
  "device_class": "none",
  "icon": "mdi:button",
  "state_topic": "homeassistant/binary_sensor/testbutton/button",
  "unique_id": "testbutton_bt",
  "payload_on": "on",
  "payload_off": "off",
  "device": {
    "identifiers": [
      "testbutton"
    ],
    "name": "testbutton",
    "mdl": "testbutton",
    "mf": "PricelessToolkit"
  }
}`

PricelessToolkit, 2024-11-24:
What you posted is MQTT topic message.

```json

{ "name": "Button", "device_class": "none", "icon": "mdi:button", "state_topic": "homeassistant/binary_sensor/testbutton/button", "unique_id": "testbutton_bt", "payload_on": "on", "payload_off": "off", "device": { "identifiers": [ "testbutton" ], "name": "testbutton", "mdl": "testbutton", "mf": "PricelessToolkit" } }

```
But isn’t the status of that topic either "on" or "off"?

I can’t check it right now since it’s 1 AM. Tomorrow, after my day job, I’ll test it and let you know!

ppkstat, 2024-11-25:
Yes, the status is either "on" or "off". The history graph shows 0 and 1 I don't know if thats normal becauseI am not very familiar with MQTT. Perhaps some pictures might help more:
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

I also flashed another device with your example and it was discovered instantly, just to check if there are any weird issues with my MQTT broker.

PricelessToolkit, 2024-11-25:
Can you add

```c
doc["bt"] = "on";
```

to ESP32_ESP-NOW_Example.ino  "ligne 76"

and test if the button appears or not.

until tomorrow.
Bay.

ppkstat, 2024-11-25:
I just did. It's not working, so it may be a bug.

PricelessToolkit, 2024-11-25:
Fixed

ppkstat, 2024-11-25:
Yes it works now! So happy to help this great project. I will try to test other data types when I get the chance.

PricelessToolkit, 2024-11-25:
Thanks!!

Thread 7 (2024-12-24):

Combine firmware ESP1 & ESP2

BoguslavskyiR, 2024-12-24:
To make self-assembly easier and reduce the chance of errors when selecting the device, I propose using one of the free pins on both chips, such as IO7 as a MASK pin. For example:

- **For ESP1:** Connect pin IO7 to GND.
- **For ESP2:** Connect pin IO7 to 3.3V.

From the software side, in the setup section, you need to add a check for the state of this pin. If `digitalRead(MaskPin) == HIGH`, it corresponds to ESP2, else ESP1

PricelessToolkit, 2024-12-24:
Hmm, nice idea!!👍 if in the future I have a project with an identical MCU I will implement that Thanks!!

Closed 2024-12-24.

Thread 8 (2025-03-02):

ESPNOW Gateway MAC Address reported as `00:00:00:00:00:00`

mnbf9rca, 2025-03-02:
I've flashed the [ESP2 code](https://github.com/PricelessToolkit/CapiBridge/tree/main/code/Gateway/ESP2), but serial monitor shows an improbable MAC address...

```
ESP-ROM:esp32c3-api1-20210207
Build:Feb  7 2021
rst:0x1 (POWERON),boot:0xc (SPI_FAST_FLASH_BOOT)
SPIWP:0xee
mode:DIO, clock div:1
load:0x3fcd5820,len:0x1144
load:0x403cc710,len:0xad8
load:0x403ce710,len:0x2f80
entry 0x403cc710

ESPNOW Gateway MAC Address:  00:00:00:00:00:00
```

PricelessToolkit, 2025-03-02:
Thanks for reporting, Fixed!

Closed 2025-03-02.

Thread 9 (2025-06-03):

CapiBridge and SX1262 based boards compatibility

Dainius-G, 2025-06-03:
For last few days I have tried to figure out how to add new sensors based Heltec Lora Esp32(V3.1) board.
Tried enabling/disabling crc, SF , Frequency, SyncWord, Preamble combinations etc
With no luck so far
Any ideas if this at all possible?
thanks.

PricelessToolkit, 2025-06-03:
1. Capibridge has the latest firmware?
2. For SX1262 sync word is 16b, so "0x1424  equivalent of CapiBridge 0x12 "

Connect CapiBridge to a PC via USB and open a serial terminal to see if it receives something.

Dainius-G, 2025-06-04:
I have updated Capibridge today. I can see you added some encryption features, thank you.
back to the issue I have with sx1262 board.
I have ttgo lora 32 v1.3(SX1276 I believe) board and Heltec Lora Esp32(V3.1)() board running identical lora parameters
only difference is I have to use Heltec_unnofficial.h to initialize the sx1262 as I could not get standard Lora.h to initialize sx1262 for some reason.
TTGO lora 32 v1.3 connects (with syncword 0x12) to CapiBridge (syncWord is 0x12) no problem [https://pastebin.com/yRq6xsJz](url)
Heltec lora 32 v3.1 does not connect (with any syncword 0x12, 0x16b or 0x1424) to  CapiBridge (syncWord is 0x12) [https://pastebin.com/T4EPQW9v](url)

Closed 2025-06-10.

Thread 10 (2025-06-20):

Upload error with new MailboxGuard firmware

kavo91, 2025-06-20:
`/Users/Mitch/Downloads/Mailbox_Guard_Sensor_CapiBridge/Mailbox_Guard_Sensor_CapiBridge.ino: In function 'String xorCipher(String)':
/Users/Mitch/Downloads/Mailbox_Guard_Sensor_CapiBridge/Mailbox_Guard_Sensor_CapiBridge.ino:62:21: warning: comparison between signed and unsigned integer expressions [-Wsign-compare]
   for (int i = 0; i < input.length(); i++) {
                   ~~^~~~~~~~~~~~~~~~
Sketch uses 7296 bytes (44%) of program storage space. Maximum is 16384 bytes.
Global variables use 253 bytes (12%) of dynamic memory, leaving 1795 bytes for local variables. Maximum is 2048 bytes.
SerialUPDI
UPDI programming for Arduino using a serial adapter
Based on pymcuprog, with significant modifications
By Quentin Bolsee and Spence Konde
Version 1.2.3 - Jan 2022
Using serial port /dev/cu.usbserial-10 at 230400 baud.
Target: attiny1616
Set fuses: ['0:0b00000000', '2:0x02', '6:0x04', '7:0x00', '8:0x00']
Action: write
File: /Users/Mitch/Library/Caches/arduino/sketches/EE8F7CEC21620CAB7F9E828E464C88AB/Mailbox_Guard_Sensor_CapiBridge.ino.hex
pymcuprog.serialupdi.physical - ERROR - Unable to open serial port '/dev/cu.usbserial-10'
Traceback (most recent call last):
  File "/Users/Mitch/Library/Arduino15/packages/megaTinyCore/hardware/megaavr/2.6.10/tools/libs/serial/serialposix.py", line 265, in open
    self.fd = os.open(self.portstr, os.O_RDWR | os.O_NOCTTY | os.O_NONBLOCK)
OSError: [Errno 16] Resource busy: '/dev/cu.usbserial-10'

During handling of the above exception, another exception occurred:

Traceback (most recent call last):
  File "/Users/Mitch/Library/Arduino15/packages/megaTinyCore/hardware/megaavr/2.6.10/tools/prog.py", line 286, in <module>
    main()
  File "/Users/Mitch/Library/Arduino15/packages/megaTinyCore/hardware/megaavr/2.6.10/tools/prog.py", line 128, in main
    return_code = pymcuprog_basic(args, fuses_dict)
  File "/Users/Mitch/Library/Arduino15/packages/megaTinyCore/hardware/megaavr/2.6.10/tools/prog.py", line 199, in pymcuprog_basic
    status = pymcu._start_session(backend,
  File "/Users/Mitch/Library/Arduino15/packages/megaTinyCore/hardware/megaavr/2.6.10/tools/libs/pymcuprog/pymcuprog_main.py", line 545, in _start_session
    backend.start_session(sessionconfig)
  File "/Users/Mitch/Library/Arduino15/packages/megaTinyCore/hardware/megaavr/2.6.10/tools/libs/pymcuprog/backend.py", line 359, in start_session
    self.programmer.setup_device(
  File "/Users/Mitch/Library/Arduino15/packages/megaTinyCore/hardware/megaavr/2.6.10/tools/libs/pymcuprog/programmer.py", line 78, in setup_device
    self.device_model = get_nvm_access_provider(self.transport,
  File "/Users/Mitch/Library/Arduino15/packages/megaTinyCore/hardware/megaavr/2.6.10/tools/libs/pymcuprog/nvm.py", line 42, in get_nvm_access_provider
    accessprovider = NvmAccessProviderSerial(transport, device_info, baud=frequency, options=options)
  File "/Users/Mitch/Library/Arduino15/packages/megaTinyCore/hardware/megaavr/2.6.10/tools/libs/pymcuprog/nvmserialupdi.py", line 54, in __init__
    self.avr = UpdiApplication(port, baud, self.dut)
  File "/Users/Mitch/Library/Arduino15/packages/megaTinyCore/hardware/megaavr/2.6.10/tools/libs/pymcuprog/serialupdi/application.py", line 70, in __init__
    self.phy = UpdiPhysical(serialport, baud_temp)
  File "/Users/Mitch/Library/Arduino15/packages/megaTinyCore/hardware/megaavr/2.6.10/tools/libs/pymcuprog/serialupdi/physical.py", line 29, in __init__
    self.initialise_serial(self.port, self.baud)
  File "/Users/Mitch/Library/Arduino15/packages/megaTinyCore/hardware/megaavr/2.6.10/tools/libs/pymcuprog/serialupdi/physical.py", line 50, in initialise_serial
    self.ser.open()
  File "/Users/Mitch/Library/Arduino15/packages/megaTinyCore/hardware/megaavr/2.6.10/tools/libs/serial/serialposix.py", line 268, in open
    raise SerialException(msg.errno, "could not open port {}: {}".format(self._port, msg))
serial.serialutil.SerialException: [Errno 16] could not open port /dev/cu.usbserial-10: [Errno 16] Resource busy: '/dev/cu.usbserial-10'
Failed programming: uploading error: exit status 1`

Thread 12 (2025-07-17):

Test AI issue

PricelessToolkit, 2025-07-17:
Can you give me an example of an ESP-NOW node minimal one so I can test if Capibridge is working, and how 2-way communication works, where I need to publish in which topic to send payload through LoRa?

AI-RedCode, 2025-07-17:
Hi! Here's a minimal example and key info to help you test ESP-NOW and 2-way communication with CapiBridge:

1. **ESP-NOW Node Minimal Example:**
For ESP-NOW, ESP2 on CapiBridge requires no initial setup—just upload the `ESP2.ino` sketch. It will automatically print its MAC address in the serial monitor. Use that MAC to have your ESP-NOW nodes send data. There is no need to configure topics for ESP-NOW since it works via direct MAC communication.

2. **2-Way Communication via LoRa:**
- To send commands back to nodes via LoRa and MQTT, publish a JSON payload to the MQTT topic:

  ```
  homeassistant/sensor/CapiBridge/command
  ```

- The JSON payload should look like:

  ```json
  {"k":"xy","id":"<NodeName>","com":"<command>"}
  ```

  - `"k"`: Your unique CapiBridge gateway key (e.g., `"xy"`)
  - `"id"`: Target node name (must match the node’s `id` in JSON)
  - `"com"`: Command string

3. **Sending Payloads from Nodes:**
Nodes send JSON strings via LoRa or ESP-NOW like:

```json
{
  "k": "xy",
  "id": "YourNodeName",
  "b": "99",
  "s": "status"
}
```

The gateway will parse these into MQTT topics dynamically.

4. **LoRa Node Minimal Code Sketch Example:**
The README includes a simple LoRa sending example with encryption keys. For ESP-NOW, your node will send directly to the MAC printed by ESP2, without MQTT topics.

5. **Arduino IDE Setup:**
Make sure you configure `config.h` in `ESP1.ino` with your gateway keys, WiFi, MQTT, and LoRa settings matching your nodes.

For details, see the README sections on:

- [2-way communication](https://github.com/PricelessToolkit/CapiBridge/tree/main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)
- ESP2 sketch for ESP-NOW MAC and usage
- Example JSON payloads and encryption keys

This should get you started testing both ESP-NOW nodes with CapiBridge and sending commands back via MQTT and LoRa.

**✅ If this answer helped, please close the issue.**
**🤖 I’m an AI and If my response is incorrect or not sufficient, don’t worry @PricelessToolkit will review this topic soon.**

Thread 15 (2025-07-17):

Test AI Issue

PricelessToolkit, 2025-07-17:
What range can I expect for ESP-NOW nodes?

AI-RedCode, 2025-07-17:
The README doesn't specify the exact range for ESP-NOW nodes, but since CapiBridge supports ESP-NOW on ESP32-C3 modules, typical ESP-NOW ranges are generally around 100 meters indoors and up to 250 meters or more in open spaces, depending on antennas and environment.

For detailed info on configuring ESP-NOW nodes and integration with CapiBridge, you can refer to the [ESP2.ino sketch configuration](https://github.com/PricelessToolkit/CapiBridge?tab=readme-ov-file#esp2ino-sketch-configuration) section. Also, make sure to connect antennas properly to ensure optimal performance (see the "Before you start" warning).

If you need further advice on antennas and cables, the README provides links for recommended antenna options.

For any additional troubleshooting or support, you can also join the [Facebook Group](https://www.facebook.com/groups/pricelesstoolkit) or open a new discussion on the GitHub repository.

**✅ If this answer helped, please close the issue.**
**🤖 I’m an AI and If my response is incorrect or not sufficient, don’t worry @PricelessToolkit will review this topic soon.**

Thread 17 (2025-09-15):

PCB Revision RA-01SH

robotsflo, 2025-09-15:
Following your August 2025 update, I bought the components to build my CAPIBRIDGE. However, I ordered the RA01-SH chip instead of the RA-01H chip used in the original design.
Does this new chip require a PCB revision or changes to the pinout between the LoRa module and the ESP1?
In parallel, I also built my own PIRBOXLITE, which seems to be working fine. But I don’t see any JSON frames coming into my CAPIBRIDGE. The ESPNOW example, however, works perfectly.

AI-RedCode, 2025-09-15:
Hi robotsflo,

Regarding your question about the RA-01SH chip (SX1262) and PCB revisions: After the August 2025 hardware update, the README confirms that the new LoRa module RA-01SH "SX1262" requires selecting the module type in your `config.h` file by enabling:

```cpp
//#define LORA_MODULE LORA_MODULE_SX1276  // SX1276 Module (orders shipped before Aug 2025)
#define LORA_MODULE LORA_MODULE_SX1262  // SX1262 Module CapiBridge v2 (orders shipped after Aug 2025)
```

This suggests that the pinout changes are handled via software configuration, and no explicit mention of PCB revisions or pinout modifications is made beyond this config change.

For your CAPIBRIDGE not receiving JSON frames from your PIRBOXLITE while ESPNOW example works fine:

- Ensure the LoRa settings on your PIRBOXLITE match those configured on the CAPIBRIDGE gateway (frequency, spreading factor, encryption, etc.).
- Check the `config.h` encryption keys and that both devices share the same `GATEWAY_KEY` and XOR encryption settings.
- You can monitor received LoRa messages by connecting the CAPIBRIDGE to a PC with the UART switch set to ESP1 and opening the Serial Monitor at 115200 baud to check for JSON strings.
- Also, verify your MQTT server and topics are correctly set for your CAPIBRIDGE to publish data.

Useful references from the README:

- Hardware modification note for RA-01SH LoRa module and config setting:
  https://github.com/PricelessToolkit/CapiBridge?tab=readme-ov-file#esp1ino-sketch-configuration
- Troubleshooting tips for missing nodes/sensors:
  https://github.com/PricelessToolkit/CapiBridge#troubleshooting
- PIRBOX-LITE is listed as supported out-of-the-box:
  https://github.com/PricelessToolkit/PirBOX-LITE

This info should help you adapt the RA-01SH chip usage without PCB changes and troubleshoot the missing JSON frames from your PIRBOXLITE.

**✅ If this answer helped, please close the issue.**
**🤖 I’m an AI and If my response is incorrect or not sufficient, don’t worry @PricelessToolkit will review this topic soon.**

PricelessToolkit, 2025-09-15:
> Following your August 2025 update, I bought the components to build my CAPIBRIDGE. However, I ordered the RA01-SH chip instead of the RA-01H chip used in the original design. Does this new chip require a PCB revision or changes to the pinout between the LoRa module and the ESP1? In parallel, I also built my own PIRBOXLITE, which seems to be working fine. But I don’t see any JSON frames coming into my CAPIBRIDGE. The ESPNOW example, however, works perfectly.

Hi,
1. The new chip requires a pinout change, so RA-01SH will not work in Capibridge. PCB files are for RA-01H
2. The Files are not updated yet on GitHub.

robotsflo, 2025-09-15:
OK, thank you. Could you upload the schematic updated for the revision with RA-01SH? The new Capibridge units since August 2025 run with this chip.

robotsflo, 2025-09-15:
I have already receive 2 pcs of ra-01sh.
When I ordered them two week ago, I have choses this chip because you wrote that is the new hardware in last batch from aug 2025 orders.

If i have known that is cause me lot of lost time to find my false soldering mistake, i would bought the good one directly. 😂

Closed 2025-09-15.

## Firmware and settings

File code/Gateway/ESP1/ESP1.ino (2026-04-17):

#include <Arduino.h>
#include "settings.h"
#include "radio.h"
#include "web_ui.h"
#include <SPI.h>
#include <WiFi.h>
#include <PubSubClient.h>
#include <WebServer.h>
#include <ArduinoJson.h>
#include <vector>
#include <math.h>
#include <stdarg.h>

// Mirror the hardware serial output into an in-memory log so the web UI can show a live Raw View terminal.
class MirroredSerial : public Print {
 public:
  explicit MirroredSerial(HardwareSerial& serial) : serial_(serial) {}

  void begin(unsigned long baud) { serial_.begin(baud); }

  size_t write(uint8_t ch) override {
    serial_.write(ch);
    mirrorChar(static_cast<char>(ch));
    return 1;
  }

  size_t write(const uint8_t* buffer, size_t size) override {
    serial_.write(buffer, size);
    for (size_t i = 0; i < size; ++i) {
      mirrorChar(static_cast<char>(buffer[i]));
    }
    return size;
  }

  size_t printf(const char* format, ...) {
    va_list args;
    va_start(args, format);
    va_list copy;
    va_copy(copy, args);
    int needed = vsnprintf(nullptr, 0, format, copy);
    va_end(copy);
    if (needed <= 0) {
      va_end(args);
      return 0;
    }
    String buffer;
    buffer.reserve(static_cast<size_t>(needed) + 1);
    char temp[needed + 1];
    vsnprintf(temp, sizeof(temp), format, args);
    va_end(args);
    write(reinterpret_cast<const uint8_t*>(temp), static_cast<size_t>(needed));
    return static_cast<size_t>(needed);
  }

  using Print::write;

 private:
  HardwareSerial& serial_;

  void mirrorChar(char ch);
};

// LoRa RX interrupts only flip this flag; the main loop does the heavier packet handling work.
volatile bool packetReceived = false;
void onReceive() { packetReceived = true; }

#define LED_PIN 2
#define BAUD 115200
#define RXPIN 18
#define TXPIN 19

#define MQTT_RETAIN true
#define BINARY_SENSOR_TOPIC "homeassistant/binary_sensor/"
#define SENSOR_TOPIC "homeassistant/sensor/"
#define CAPIBRIDGE_LWT_TOPIC "capibridge/availability"
#define CAPIBRIDGE_RSSI_TOPIC "homeassistant/sensor/CapiBridge/rssi"
#define CAPIBRIDGE_COMMAND_TOPIC "homeassistant/sensor/CapiBridge/command"
#define AVAIL_ON  "online"
#define AVAIL_OFF "offline"

const char* FIRMWARE_VERSION = "V1.3";

// Global gateway state shared across setup, loop, radio handling, MQTT, and the web API.
RuntimeRadio radio;
GatewaySettings settings;
SettingsStore settingsStore;
WebServer server(80);
WiFiClient espClient;
PubSubClient client(espClient);
std::vector<String> publishedDiscovery;

static constexpr size_t MAX_SERIAL_LOG = 120;
std::vector<String> serialLog;
String serialLineBuffer;

// Keep only the newest serial lines so the browser-side Raw View stays bounded in RAM.
void pushSerialLogLine(const String& line) {
  if (serialLog.size() >= MAX_SERIAL_LOG) {
    serialLog.erase(serialLog.begin());
  }
  String clipped = line.length() <= 480 ? line : line.substring(0, 480) + "\n... truncated ...";
  serialLog.push_back(clipped);
}

// Build log lines one character at a time and flush them whenever Serial prints a newline.
void MirroredSerial::mirrorChar(char ch) {
  if (ch == '\r') {
    return;
  }
  if (ch == '\n') {
    pushSerialLogLine(serialLineBuffer);
    serialLineBuffer = "";
    return;
  }
  serialLineBuffer += ch;
  if (serialLineBuffer.length() > 480) {
    serialLineBuffer.remove(0, serialLineBuffer.length() - 480);
  }
}

static MirroredSerial SerialMirror(::Serial);
#define Serial SerialMirror

String mqttMessage = "";
bool newCommandReceived = false;
bool accessPointActive = false;
String accessPointSsid = "";
unsigned long LedStartTime = 0;
unsigned long diagTimer = 60000;
unsigned long lastDiagTimer = 0;
unsigned long lastWifiTry = 0;
unsigned long lastMqttAttempt = 0;
unsigned long rebootAt = 0;

static constexpr size_t MAX_TRAFFIC_LOG = 30;
static constexpr size_t MAX_WORKING_NODES = 48;
static constexpr size_t MAX_TRAFFIC_TEXT = 480;

struct TrafficEntry {
  unsigned long atMs;
  String source;
  String status;
  String nodeId;
  int rssi;
  String raw;
  String pretty;
};

struct WorkingNodeEntry {
  unsigned long atMs;
  String source;
  String status;
  String nodeId;
  int rssi;
  bool hasBattery;
  String battery;
};

std::vector<TrafficEntry> trafficLog;
std::vector<WorkingNodeEntry> workingNodes;

// Discovery tracking avoids re-sending the same Home Assistant config unless the user asked for it.
static bool discoveryPublishedFor(const String &id, const String &suffix) {
  String key = id + "|" + suffix;
  for (const auto &v : publishedDiscovery) {
    if (v == key) return true;
  }
  return false;
}

static void markDiscoveryPublished(const String &id, const String &suffix) {
  publishedDiscovery.push_back(id + "|" + suffix);
}

// Small formatting helpers used by the status API and boot diagnostics.
String ipToString(const IPAddress& ip) {
  return ip.toString();
}

String formatUptime(unsigned long ms) {
  unsigned long totalSeconds = ms / 1000;
  unsigned long days = totalSeconds / 86400;
  totalSeconds %= 86400;
  unsigned long hours = totalSeconds / 3600;
  totalSeconds %= 3600;
  unsigned long minutes = totalSeconds / 60;
  unsigned long seconds = totalSeconds % 60;

  char buffer[40];
  snprintf(buffer, sizeof(buffer), "%lud %02lu:%02lu:%02lu", days, hours, minutes, seconds);
  return String(buffer);
}

bool hasConfiguredWifi() {
  return strlen(settings.wifiSsid) > 0 && strcmp(settings.wifiSsid, "CHANGE_ME") != 0;
}

bool hasConfiguredMqtt() {
  return strlen(settings.mqttServer) > 0 && strcmp(settings.mqttServer, "CHANGE_ME") != 0;
}

bool webUiPasswordEnabled() {
  return strlen(WEBUI_PASSWORD) > 0;
}

bool ensureWebUiAuth() {
  if (!webUiPasswordEnabled()) {
    return true;
  }

  if (server.authenticate(WEBUI_USERNAME, WEBUI_PASSWORD)) {
    return true;
  }

  server.requestAuthentication(BASIC_AUTH, "CapiBridge", "Enter Web UI password");
  return false;
}

String settingsSourceLabel() {
  return settingsStore.wasLoadedFromFlash() ? "Saved settings" : "Upload defaults";
}

String formatTrafficTime(unsigned long atMs) {
  unsigned long totalSeconds = atMs / 1000;
  unsigned long hours = (totalSeconds / 3600) % 24;
  unsigned long minutes = (totalSeconds / 60) % 60;
  unsigned long seconds = totalSeconds % 60;
  char buffer[16];
  snprintf(buffer, sizeof(buffer), "%02lu:%02lu:%02lu", hours, minutes, seconds);
  return String(buffer);
}

String clipTrafficText(const String& text) {
  if (text.length() <= MAX_TRAFFIC_TEXT) {
    return text;
  }
  return text.substring(0, MAX_TRAFFIC_TEXT) + "\n... truncated ...";
}

String formatJsonPretty(const String& raw) {
  StaticJsonDocument<2048> doc;
  if (deserializeJson(doc, raw)) {
    return raw;
  }

  String pretty;
  serializeJsonPretty(doc, pretty);
  return pretty;
}

void updateWorkingNode(const String& source, const String& raw, const String& status, int rssi, const String& nodeId) {
  if (nodeId.isEmpty()) {
    return;
  }

  for (auto it = workingNodes.begin(); it != workingNodes.end(); ++it) {
    if (it->nodeId == nodeId) {
      workingNodes.erase(it);
      break;
    }
  }

  WorkingNodeEntry entry;
  entry.atMs = millis();
  entry.source = source;
  entry.status = status;
  entry.nodeId = nodeId;
  entry.rssi = rssi;
  entry.hasBattery = false;
  entry.battery = "";

  StaticJsonDocument<512> preview;
  if (!deserializeJson(preview, raw) && preview["b"].is<JsonVariantConst>()) {
    entry.hasBattery = true;
    entry.battery = preview["b"].as<String>();
  }

  workingNodes.push_back(entry);

  if (workingNodes.size() > MAX_WORKING_NODES) {
    workingNodes.erase(workingNodes.begin());
  }
}

// Store the most recent parsed payloads for the Monitoring page.
void pushTrafficEntry(const String& source, const String& raw, const String& status, int rssi, const String& nodeId = "") {
  TrafficEntry entry;
  entry.atMs = millis();
  entry.source = source;
  entry.status = status;
  entry.nodeId = nodeId;
  entry.rssi = rssi;
  entry.raw = clipTrafficText(raw);
  entry.pretty = clipTrafficText(formatJsonPretty(raw));

  if (trafficLog.size() >= MAX_TRAFFIC_LOG) {
    trafficLog.erase(trafficLog.begin());
  }
  trafficLog.push_back(entry);
  updateWorkingNode(source, entry.raw, status, rssi, nodeId);
}

// When normal WiFi is missing or broken, expose a local setup AP so the web UI stays reachable.
void startConfigPortal() {
  if (accessPointActive) {
    return;
  }

  WiFi.mode(WIFI_AP_STA);
  char suffix[7];
  snprintf(suffix, sizeof(suffix), "%06X", static_cast<uint32_t>(ESP.getEfuseMac() & 0xFFFFFF));
  accessPointSsid = String("CapiBridge-Setup-") + suffix;
  WiFi.softAP(accessPointSsid.c_str());
  accessPointActive = true;

  Serial.println();
  Serial.println("Setup AP enabled");
  Serial.print("AP SSID: ");
  Serial.println(accessPointSsid);
  Serial.print("AP IP: ");
  Serial.println(WiFi.softAPIP());
}

void stopConfigPortal() {
  if (!accessPointActive) {
    return;
  }

  WiFi.softAPdisconnect(true);
  accessPointActive = false;
  accessPointSsid = "";
  WiFi.mode(WIFI_STA);
}

// Try to join the configured WiFi network first, then fall back to AP mode for setup.
void setup_wifi() {
  Serial.println();
  WiFi.persistent(false);
  WiFi.mode(WIFI_STA);

  if (!hasConfiguredWifi()) {
    Serial.println("WiFi not configured yet. Starting setup AP.");
    startConfigPortal();
    return;
  }

  Serial.print("Connecting to ");
  Serial.println(settings.wifiSsid);
  WiFi.begin(settings.wifiSsid, settings.wifiPassword);

  unsigned long start = millis();
  while (WiFi.status() != WL_CONNECTED && millis() - start < 20000) {
    delay(500);
    Serial.print(".");
  }

  if (WiFi.status() == WL_CONNECTED) {
    Serial.println();
    Serial.println("WiFi connected");
    Serial.print("IP address: ");
    Serial.println(WiFi.localIP());
  } else {
    Serial.println("\nWiFi connect timeout; setup AP enabled for configuration.");
    startConfigPortal();
  }
}

// MQTT commands are buffered here and handled later from loop() so callback work stays minimal.
void callback(char* incomingTopic, byte* payload, unsigned int length) {
  String topicStr = String(incomingTopic);
  mqttMessage = "";

  for (unsigned int i = 0; i < length; i++) {
    mqttMessage += static_cast<char>(payload[i]);
  }

  if (topicStr == CAPIBRIDGE_COMMAND_TOPIC && mqttMessage.length() > 0) {
    newCommandReceived = true;
  }
}

// Reconnect to the broker with a retry delay, and re-subscribe to the command topic on success.
void reconnectMqtt() {
  if (client.connected() || WiFi.status() != WL_CONNECTED || !hasConfiguredMqtt()) {
    return;
  }

  if (millis() - lastMqttAttempt < 5000) {
    return;
  }

  lastMqttAttempt = millis();
  client.setBufferSize(2048);
  client.setServer(settings.mqttServer, settings.mqttPort);
  client.setCallback(callback);

  String clientId = "CapiBridge-" + String(static_cast<uint32_t>(ESP.getEfuseMac()), HEX);

  bool ok = client.connect(
    clientId.c_str(),
    settings.mqttUsername,
    settings.mqttPassword,
    CAPIBRIDGE_LWT_TOPIC, 0, true, AVAIL_OFF
  );

  if (ok) {
    Serial.println("MQTT connected");
    client.subscribe(CAPIBRIDGE_COMMAND_TOPIC);
    client.publish(CAPIBRIDGE_LWT_TOPIC, AVAIL_ON, true);
  } else {
    Serial.print("MQTT failed, rc=");
    Serial.println(client.state());
  }
}

// LoRa and ESP-NOW share the same XOR obfuscation helper.
void xorBuffer(uint8_t* buf, size_t len) {
  const int keyLen = settings.encryptionKeyLength;
  if (keyLen <= 0) {
    return;
  }

  for (size_t i = 0; i < len; ++i) {
    buf[i] ^= settings.encryptionKey[i % keyLen];
  }
}

// Publish Home Assistant discovery topics only once per node/entity unless forced by settings.
void publishSensorDiscoveryOnce(
  const String& nodeId,
  const String& suffix,
  const String& friendlyName,
  const String& icon,
  const String& device_class,
  const String& unit,
  bool isBinarySensor,
  bool hasStateClassMeasurement,
  bool isDiagnostic = false
) {
  if (!client.connected()) {
    return;
  }

  if (!settings.discoveryEveryPacket && discoveryPublishedFor(nodeId, suffix)) {
    return;
  }

  StaticJsonDocument<768> cfg;
  cfg["name"] = friendlyName;
  if (icon.length()) cfg["icon"] = icon;
  if (device_class.length()) cfg["device_class"] = device_class;
  if (unit.length()) cfg["unit_of_measurement"] = unit;
  if (isDiagnostic) cfg["entity_category"] = "diagnostic";

  String baseStateTopic = String(isBinarySensor ? BINARY_SENSOR_TOPIC : SENSOR_TOPIC) + nodeId + suffix;
  cfg["state_topic"] = baseStateTopic;
  cfg["unique_id"] = nodeId + suffix;
  cfg["availability_topic"] = CAPIBRIDGE_LWT_TOPIC;

  if (isBinarySensor) {
    cfg["payload_on"] = "on";
    cfg["payload_off"] = "off";
  }

  if (hasStateClassMeasurement) {
    cfg["state_class"] = "measurement";
  }

  JsonObject dev = cfg.createNestedObject("device");
  JsonArray identifiers = dev.createNestedArray("identifiers");
  identifiers.add(nodeId);
  dev["name"] = nodeId;
  dev["model"] = nodeId;
  dev["manufacturer"] = "PricelessToolkit";

  String payload;
  serializeJson(cfg, payload);

  String configTopic = String(isBinarySensor ? BINARY_SENSOR_TOPIC : SENSOR_TOPIC) + nodeId + suffix + "/config";
  client.publish(configTopic.c_str(), payload.c_str(), MQTT_RETAIN);

  if (!settings.discoveryEveryPacket) {
    markDiscoveryPublished(nodeId, suffix);
  }
}

static String fmtFloat(double v, uint8_t digits) {
  char buf[32];
  dtostrf(v, 0, digits, buf);
  return String(buf);
}

// Publish a single sensor field to MQTT if that key exists in the incoming payload.
void publishKeyIfPresent(const JsonDocument& doc, const char* key, const String& nodeId, const String& topicSuffix, bool isBinary, bool convertForHA = false) {
  if (!client.connected() || !doc.containsKey(key)) return;

  String stateTopic = String(isBinary ? BINARY_SENSOR_TOPIC : SENSOR_TOPIC) + nodeId + topicSuffix;

  if (isBinary) {
    String val = doc[key].as<String>();
    val.toLowerCase();
    if (val == "1" || val == "true") val = "on";
    if (val == "0" || val == "false") val = "off";
    if (val != "on" && val != "off") {
      val = (doc[key].as<String>().length() > 0) ? "on" : "off";
    }
    client.publish(stateTopic.c_str(), val.c_str(), MQTT_RETAIN);
  } else {
    if (doc[key].is<float>() || doc[key].is<double>() || doc[key].is<long>() || doc[key].is<int>()) {
      double v = doc[key].as<double>();
      if (convertForHA) v = v / 1000.0;
      String val = fmtFloat(v, convertForHA ? 3 : 2);
      client.publish(stateTopic.c_str(), val.c_str(), MQTT_RETAIN);
    } else {
      String val = doc[key].as<String>();
      client.publish(stateTopic.c_str(), val.c_str(), MQTT_RETAIN);
    }
  }
}
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
void loop() {
  server.handleClient();
  maybeReboot();

  // ESP-NOW packets arrive over the secondary UART with a 2-byte length prefix from ESP2.
  if (Serial1.available() >= 2) {
    uint16_t L = 0;
    if (Serial1.readBytes(reinterpret_cast<char*>(&L), 2) == 2 && L > 0 && L <= 512) {
      static uint8_t buf[513];
      size_t got = 0;
      unsigned long start = millis();

      while (got < L && (millis() - start) < 100) {
        got += Serial1.readBytes(reinterpret_cast<char*>(buf) + got, L - got);
      }

      if (got == L) {
        if (settings.rowDebug) {
          Serial.print("ESP-NOW Encrypted bytes: ");
          for (size_t i = 0; i < L; i++) {
            Serial.printf("%02X ", buf[i]);
          }
          Serial.println();
        }

        if (settings.espnowEncryption) {
          xorBuffer(buf, L);
        }

        buf[L] = 0;
        String serialrow = String(reinterpret_cast<char*>(buf));
        parseIncomingPacket("ESP-NOW", serialrow);
        StaticJsonDocument<64> preview;
        if (!deserializeJson(preview, serialrow)) {
          Serial.print("ESP-NOW Message Received: ");
          Serial.println(serialrow);
        } else {
          Serial.println("ESP-NOW Message Received: [invalid json payload omitted]");
        }
      } else {
        while (Serial1.available()) Serial1.read();
      }
    } else {
      while (Serial1.available()) Serial1.read();
    }
  }

  // LoRa packets are handled after the interrupt flag is raised, then the radio is re-armed for RX.
  if (packetReceived) {
    packetReceived = false;

    uint8_t buf[256];
    size_t len = radio.getPacketLength(true);
    if (len == 0 || len > sizeof(buf)) len = sizeof(buf);

    int16_t state = radio.readData(buf, len);
    radio.startReceive();

    if (state == RADIOLIB_ERR_NONE) {
      digitalWrite(LED_PIN, LOW);
      LedStartTime = millis();

      if (settings.rowDebug) {
        Serial.print("LoRa Encrypted bytes: ");
        for (size_t i = 0; i < len; i++) {
          Serial.printf("%02X ", buf[i]);
        }
        Serial.println();
      }

      if (settings.loraEncryption) {
        xorBuffer(buf, len);
      }

      String recv(reinterpret_cast<char*>(buf), len);
      StaticJsonDocument<2048> rx;
      DeserializationError e = deserializeJson(rx, recv);
      if (!e) {
        float packetRssi = radio.getRSSI();
        rx["r"] = packetRssi;
        String status;
        String nodeId;
        ensureDiscoveryAndPublish(rx, status, nodeId);
        String logged;
        serializeJson(rx, logged);
        pushTrafficEntry("LoRa", logged, status, static_cast<int>(lround(packetRssi)), nodeId);
        Serial.print("LoRa Message Received: ");
        serializeJson(rx, Serial);
        Serial.println();
      } else {
        Serial.print("RX JSON parse error: ");
        Serial.println(e.f_str());
        String logged = String("RX JSON parse error: ") + e.f_str();
        pushTrafficEntry("LoRa", logged, "invalid_json", static_cast<int>(lround(radio.getRSSI())));
      }
    } else {
      Serial.print("readData() error ");
      Serial.println(state);
    }
  }

  if (millis() - LedStartTime >= 100) {
    digitalWrite(LED_PIN, HIGH);
  }

  maintainWifi();
  reconnectMqtt();
  client.loop();
  diag();
  SendESPNOWCommands();
  SendLoRaCommands();
}

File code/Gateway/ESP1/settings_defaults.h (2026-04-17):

#pragma once

#define LORA_MODULE_SX1262 1
#define LORA_MODULE_SX1276 2
#define LORA_MODULE_SX1268 3

// Internal fallback defaults for settings stored in flash.
// Users can change these from the Web UI after first boot, so they stay out of
// the smaller user-facing config.h file.

//////////////////////////////// SECURITY /////////////////////////////////////

#define GATEWAY_KEY "xy"                           // Must match the sensor key.
#define LoRa_Encryption true                       // Global LoRa encryption toggle.
#define ESPNOW_Encryption false                    // Global ESP-NOW encryption toggle.
#define encryption_key_length 4                    // Must match the XOR key array length.
#define encryption_key { 0x4B, 0xA3, 0x3F, 0x9C }  // Multi-byte XOR key (2-16 bytes).

/////////////////////////////////// MQTT //////////////////////////////////////

#define MQTT_USERNAME "test"
#define MQTT_PASSWORD "test123"
#define MQTT_SERVER "192.168.99.2"
#define MQTT_PORT 1883
#define DISCOVERY_EVERY_PACKET true  // False sends discovery once per boot.

////////////////////////////// LORA DEFAULTS //////////////////////////////////

// Bandwidth vs SF support (SX126x):
// 125 kHz: SF5-SF9
// 250 kHz: SF5-SF10
// 500 kHz: SF5-SF11

#define LORA_SIGNAL_BANDWIDTH 250.0  // kHz: 125.0, 250.0, 500.0
#define LORA_SPREADING_FACTOR 10     // SX126x: 5-11, SX1276: 6-12
#define LORA_CODING_RATE 5           // 5-8 => coding rate 4/5 .. 4/8
#define LORA_SYNC_WORD 0x12          // Default 0x12, normally unchanged.
#define LORA_PREAMBLE_LENGTH 12      // 6..65535
#define LORA_TX_POWER 20             // Check regulatory limits for your region.

//////////////////////////////// DIAGNOSTICS //////////////////////////////////

#define ROW_Debug false  // Print RAW hex instead of JSON.

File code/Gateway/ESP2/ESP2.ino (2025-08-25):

#include <Arduino.h>
#include <esp_now.h>
#include <WiFi.h>
#include <esp_wifi.h>   // esp_wifi_start(), esp_wifi_set_channel(), esp_wifi_get_mac()
#include <esp_err.h>    // esp_err_to_name()

// ---------- Pins / Serial ----------
#define LED_PIN 2
#define BAUD   115200
#define RXPIN  18        // UART from ESP1 (gateway)
#define TXPIN  19

// ---------- ESPNOW settings ----------
#define ESPNOW_WIFI_CHANNEL 1   // MUST match your receivers (1..13)

// Broadcast address (send to ALL devices on same channel)
static const uint8_t BROADCAST_MAC[6] = { 0xFF,0xFF,0xFF,0xFF,0xFF,0xFF };

unsigned long LedStartTime = 0;

// Payload struct (keep in sync with your nodes)
typedef struct {
  char json[250];   // text payload (max 249 chars + null)
} struct_message;

// -------------------- Helpers --------------------

// Print STA MAC; return true if it’s valid (not all zeros)
static bool printStaMac() {
  uint8_t mac[6] = {0};
  if (esp_wifi_get_mac(WIFI_IF_STA, mac) != ESP_OK) {
    Serial.println("esp_wifi_get_mac failed");
    return false;
  }
  bool allZero = true;
  for (int i = 0; i < 6; i++) if (mac[i] != 0x00) { allZero = false; break; }

  Serial.print("My MAC: ");
  if (allZero) {
    Serial.println("00:00:00:00:00:00");
  } else {
    for (int i = 0; i < 6; i++) { if (i) Serial.print(':'); Serial.printf("%02X", mac[i]); }
    Serial.println();
  }
  return !allZero;
}

// Send a text line via ESPNOW broadcast
static bool sendEspNowBroadcast(const String& line) {
  struct_message out{};
  size_t n = min(line.length(), sizeof(out.json) - 1);
  memcpy(out.json, line.c_str(), n);
  out.json[n] = '\0';

  esp_err_t err = esp_now_send(BROADCAST_MAC, reinterpret_cast<const uint8_t*>(&out), sizeof(out));
  if (err != ESP_OK) {
    Serial.print("esp_now_send() error: ");
    Serial.println(esp_err_to_name(err));
    return false;
  }
  return true;
}

// -------------------- Callbacks --------------------

// Receive callback (IDF v5 style)
void OnDataRecv(const esp_now_recv_info_t *info, const uint8_t *data, int len) {
  uint16_t L = (uint16_t)len;
  Serial1.write((uint8_t*)&L, 2);   // length prefix (little-endian)
  Serial1.write(data, len);         // raw encrypted bytes
  digitalWrite(LED_PIN, LOW);
  LedStartTime = millis();
}



// Send callback
#if defined(ESP_IDF_VERSION_MAJOR) && (ESP_IDF_VERSION_MAJOR >= 5)
// IDF v5 (Arduino core 3.x): wifi_tx_info_t*, field name is des_addr
void OnDataSent(const wifi_tx_info_t* info, esp_now_send_status_t status) {
  Serial.print("ESP-NOW send -> ");
  Serial.println(status == ESP_NOW_SEND_SUCCESS ? "SUCCESS" : "FAIL");
}
#else
// IDF v4 (Arduino core 2.x): legacy signature
void OnDataSent(const uint8_t* mac, esp_now_send_status_t status) {
  Serial.print("ESP-NOW send -> ");
  Serial.println(status == ESP_NOW_SEND_SUCCESS ? "SUCCESS" : "FAIL");
}
#endif

// -------------------- Setup / Loop --------------------

void setup() {
  Serial1.begin(BAUD, SERIAL_8N1, RXPIN, TXPIN); // ESP2 <-> ESP1 link
  Serial.begin(115200);
  delay(100);

  pinMode(LED_PIN, OUTPUT);
  digitalWrite(LED_PIN, HIGH); // LED OFF

  // Bring up Wi-Fi STA cleanly
  WiFi.persistent(false);
  WiFi.mode(WIFI_STA);
  esp_wifi_set_ps(WIFI_PS_NONE); // better ESPNOW reliability
  esp_wifi_start();              // ensure driver started
  delay(50);

  // Verify MAC not zero; retry once if needed
  if (!printStaMac()) {
    Serial.println("STA MAC is zero, restarting WiFi driver...");
    esp_wifi_stop();
    delay(50);
    esp_wifi_start();
    delay(100);
    printStaMac();
  }

  // Lock ESPNOW channel (must match your receivers)
  esp_wifi_set_promiscuous(true);
  esp_wifi_set_channel(ESPNOW_WIFI_CHANNEL, WIFI_SECOND_CHAN_NONE);
  esp_wifi_set_promiscuous(false);

  Serial.print("ESPNOW Channel: ");
  Serial.println(ESPNOW_WIFI_CHANNEL);

  // Init ESPNOW
  esp_err_t e = esp_now_init();
  if (e != ESP_OK) {
    Serial.print("Error initializing ESP-NOW: ");
    Serial.println(esp_err_to_name(e));
    return;
  }

  // (Optional) Some builds are happier if we also add broadcast as a peer.
  // It's not strictly required for broadcast, but harmless:
  esp_now_peer_info_t bcast{};
  memcpy(bcast.peer_addr, BROADCAST_MAC, 6);
  bcast.ifidx   = WIFI_IF_STA;
  bcast.channel = ESPNOW_WIFI_CHANNEL;
  bcast.encrypt = false;
  e = esp_now_add_peer(&bcast);
  if (e != ESP_OK && e != ESP_ERR_ESPNOW_EXIST) {
    Serial.print("add_peer(broadcast) warning: ");
    Serial.println(esp_err_to_name(e));
  }

  esp_now_register_recv_cb(OnDataRecv);
  esp_now_register_send_cb(OnDataSent);
}

void loop() {
  // Read a line from ESP1 and broadcast it over ESPNOW
  if (Serial1.available() > 0) {
    String line = Serial1.readStringUntil('\n'); // ESP1 sends newline-terminated
    line.trim();
    if (line.length()) {
      if (sendEspNowBroadcast(line)) {
        Serial.print("Broadcast: ");
        Serial.println(line);
        digitalWrite(LED_PIN, LOW);
        LedStartTime = millis();
      } else {
        Serial.println("ESP-NOW send failed");
      }
    }
  }

  // Turn LED off after 100 ms
  if (millis() - LedStartTime >= 100) {
    digitalWrite(LED_PIN, HIGH);
  }
}

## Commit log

2024-05-26 3D enclosure
    [CapiBridge_Case.SLDPRT, CapiBridge_Case.STL, CapiBridge_Case_lit.SLDPRT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]
2024-06-15 Battery in percent
2024-11-25 Button autodiscovery
    Button autodiscovery
2024-11-25 Button autodiscovery
2024-11-25 Icon for pressure
2025-07-07 Update ESP1.ino
    Typo fixing
    [ESP1.ino]
2026-04-17 Add WebUI section and update README content
    Added a new WebUI section for configuration and monitoring, along with updates on supported sensors and recent changes.
2026-10-29 Fix
    Fixed WebUI Monitoring page crash with ArduinoJson 6
2026-10-29 Change Arduino IDE version to 3.3.12
    Updated Arduino IDE version in the README.
2026-10-29 included lib update
    ArduinoJson 7.4.3
